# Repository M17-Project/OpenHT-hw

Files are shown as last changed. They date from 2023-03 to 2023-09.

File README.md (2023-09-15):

# OpenHT-hw
Hardware part of the OpenHT - an open-source, SDR handheld transceiver.

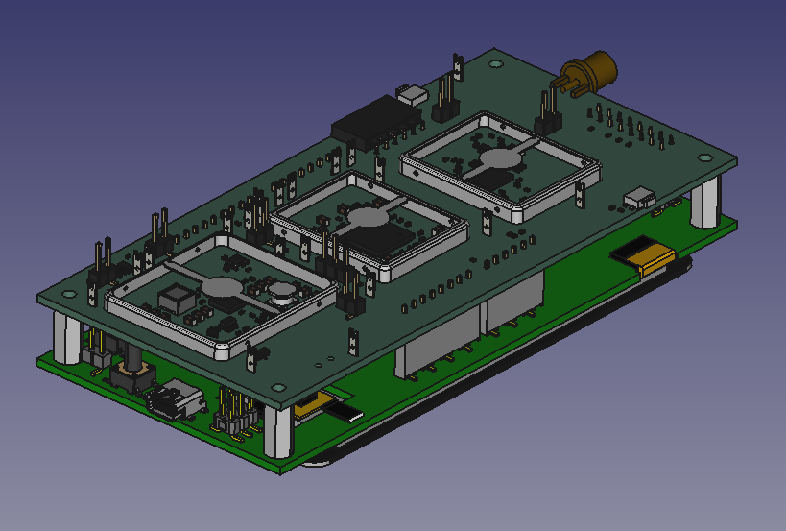
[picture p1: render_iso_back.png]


## Description
The device is a complete, low RF power I/Q transceiver, supporting virtually any mode (including [M17](https://m17project.org) and [FreeDV](https://freedv.org)).
It is built around the [AT86RF215 chip](https://www.microchip.com/en-us/product/AT86RF215) by Microchip/Atmel
and [LIFCL-40-9SG72C](https://www.latticesemi.com/Products/FPGAandCPLD/CrossLink-NX) FPGA from Lattice as a shield for [32F469IDISCOVERY](https://www.st.com/en/evaluation-tools/32f469idiscovery.html). It is possible to use the board with other MCU platforms.

Technical details:
- frequency range: 389.5 - 480, 2400 - 2483.5 MHz (RX, TX frequency range is limited by your local laws)
- RF power output: <14dBm (<25mW)

## Assembly tips and U204 issue
After the board has been populated, perform the steps below:
1) Remove JP201 (undervoltage lock-out).
2) Remove U204 (you need to take the lower shield off).
3) Using a copper wire, connect `VIN` and `VBAT`.
4) Secure goldpin headers in place by putting them on the DISCO board (Arduino male connector and the 2x8 female connector) and solder them.
5) Populate JP401 and short the two left pins,`JTAG_EN` to `GND`, "OFF" position.
6) Prepare a micro-SD card with the FPGA image, its filename should be `OpenHT_impl_1.bit`. The SD card has to be preformatted with FAT32.
7) Plug the mini-USB port and flash the firmware from the `main` branch.
8) In the GUI, tap on the cog icon (upper left corner), then press the `Erase NOR` button. After a few seconds (about 3), press the `SD to NOR` button and wait a few seconds more.
9) After the flashing is done, press and hold the power-on button for at least 1.5 seconds. The "LED" next to the cog icon should light up in green.

Step 8) needs to be performed only *once* for a fresh FPGA image. After that, the image is transferred to the NOR flash and is supposed to be retrieved by the FPGA automagically.
It is highly recommended to use terminal for getting debug info. The terminal is 115,200 baud, 8n1, over the COM port exposed by the DISCO board.

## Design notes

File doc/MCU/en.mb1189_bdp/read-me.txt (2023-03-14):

******************************************************************************
* @file    readme.txt
* @author  MCD Application Team
* @version 3.0
* @date    11-March-2022  
* @brief   MB1189 board design project files package
******************************************************************************
* COPYRIGHT(c) 2022 STMicroelectronics
*
* The Open Platform License Agreement (“Agreement”) is a binding legal contract
* between you ("You") and STMicroelectronics International N.V. (“ST”), a
* company incorporated under the laws of the Netherlands acting for the purpose
* of this Agreement through its Swiss branch 39, Chemin du Champ des Filles,
* 1228 Plan-les-Ouates, Geneva, Switzerland.
*
* By using the enclosed reference designs, schematics, PC board layouts, and
* documentation, in hardcopy or CAD tool file format (collectively, the
* “Reference Material”), You are agreeing to be bound by the terms and
* conditions of this Agreement. Do not use the Reference Material until You
* have read and agreed to this Agreement terms and conditions. The use of
* the Reference Material automatically implies the acceptance of the Agreement
* terms and conditions.
*
* The complete Open Platform License Agreement can be found on www.st.com/opla.
******************************************************************************

========================
* 2.0 -  11-March-2022 
========================
    + Added revision B-08 with FRD400B25025-A-CTK display
    - Allegro design files

    + Added revision C-01.
    - Altium design files

========================
* 1.0 - 13-January-2016
========================
    + First official release with Rev B-07 .
    - Allegro design files

******************* (C) COPYRIGHT 2022 STMicroelectronics *****END OF FILE

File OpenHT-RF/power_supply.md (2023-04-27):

# Design and dimensioning of the power supply stage

## Electrical requirements

* Three output rails:
    * 3.3 V
    * 1.8 V
    * 1.0 V

* FPGA requirements
    * Manufacturer recommends a regulation accurate within 3% of the optimum voltage for the DC power supplies
        * 3.3 V -> [3.2 V - 3.4 V], or deviation of maximum 99 mV
        * 1.8 V -> [1.746 V - 1.854 V], or deviation of maximum 54 mV
        * 1.0 V -> [0.97 V - 1.03 V], or deviation of maximum 30 mV
    * An additional recommendations advices to target less than 0.25% peak noise for the PLLs supplies. In this project, only VCCPLL_ULC is connected and supplied with 1.0 V. This implies a maximum voltage ripple on the 1.0 V rail of 2.5 mV.

    Thus the 1.0 V must be particularly noise-free.

## Choice of components

It was decided to pick a buck converter to keep a good power efficiency. The triple-output buck TPS65261 from Texas Instrument was picked because it fills the constraint of being low quiescent current, input voltage range comprising 6 V-8.4 V (for a 2-cells lithium battery) and good light-load efficiency. However, at light load, the output voltage ripple can become quite important (about 20 mV). This could cause problems for the 1.0 V of the FPGA which requires an input voltage with an error margin of +-3%. Thus the 1.0 V rail will be derived from the 1.8 V rail using a high PSRR LDO.

## Buck-converter dimensioning

### Common

 * Switching frequency: 400kHz -> Rosc = 110 kR
 * Soft start: ~1 ms -> Css = 18 nF
 * UVLO: when Vbat reaches 6 V (6.0 V falling, 6.2 V rising)
    * R1 = 200 kR
    * R2 = 47.58 kR -> 47.5kR
    * Reverse calculation gives 6.209 V rising, 6.009 V falling

### Buck 1

 * Output: 3.3 V -> R1 = 9.53 kR, R2 = 43 kR (0.1% tolerance)

    |        | Min.    | Nom.    | Max.    |
    |--------|---------|---------|---------|
    | V      | 3.269 V | 3.307 V | 3.346 V |
    | %      | -0.95   | 0.22    | 1.39    |
    | Margin | 68 mV   |         | 53 mV   |

    N.B. The tolerance takes into account the tolerance of the feedback voltage reference (1%).

 * Output current: 500 mA (max. for MCU is 290 mA, max for Xcver is 80 mA. Keep room for the rest of the system (audio, FPGA, ...))
 Switching 

 * Inductor choice 
    * Value: 33 uH (LIR = 0.3)
        * Iripple = 150 mA
        * ILrms = 501 mA
        * ILpeak = 575 mA
        * ILpeak(PSM mode) = 230 mA
    The reference LSXND5050XKT330MMG is pre-picked. Max current is 800 mA, saturation current is 1.15 A, series resistance is 225 mOhm (295 mOhm max.).
* Output capacitor
    * Based on modulator pole: Does not really influence loop compensation calculation.
    * Based on Vout ripple: Voripple of 2% of 3.3 V -> 0.7uF, max Resr of 0.45 Ohm.
    * Based on load regulation: Max drop in Vout of 2% for an increase in current of 100 mA (i.e. a bit more than the Xcvr transmitting) -> 7.5 uF

    The minimum output capacitor value should therefore be 7.5 uF. The Resr should be below 0.45 Ohm. Several capacitors should be placed in parallel to help satisfy this requirement.
    Use 3 ceramic capacitors of 4.7 uF with X5R or better dielectric.

* Input capacitor
    * Using the same capacitor network as the output capacitor would lead to 22 mV of input ripple. 
    * It is recommended to use a large enough footprint so that this value can be increased later on if needed.

* Loop compensation
    * Cross over frequency fc = 1/10 of fsw or 40 kHz
    * Rc = 1595 Ohm -> rounded to 1600 Ohm
    * Cc (Rl = 3.3 V/0.5 A = 6.6 Ohm) = 58 nF, rounded up to 68 nF
    * Cb = 29 pF, rounded down to 27 pF (for a Resr of 3.3 mOhm)
    * Cff = 460 pF (https://www.ti.com/lit/an/slva466a/slva466a.pdf), rounded to 470 pF

 ### Buck 2

 * Output: 1.8V -> R1 = 10 kR, R2 = 20 kR (0.1% tolerance)

    |        | Min.    | Nom.  | Max.   |
    |--------|---------|-------|--------|
    | V      | 1.779 V | 1.8 V | 1.82 V |
    | %      | -1.13   | 0     | 1.13   |
    | Margin | 33 mV   |       | 34 mV  |

    N.B. The tolerance takes into account the tolerance of the feedback voltage reference (1%).
 * Output current: 250 mA. Picking a lower current would not make much sense as the devices goes into PSM when below 230 mA.

 * Inductor choice
    * Value: 47 uH (LIR = 0.3)
        * Iripple = 75 mA
        * ILrms = 251 mA
        * ILpeak = 288 mA
        * ILpeak (PSM) = 230mA

    The reference 74406043470 is pre-picked. Max current is 970 mA, saturation current is 560 mA, series resistance is 260 mOhm.

* Output capacitor   
    * Based on modulator pole: Does not really influence loop compensation calculation.
    * Based on Vout ripple: Voripple of max 25mV -> 0.94uF, max Resr of 0.33 Ohm.
    * Based on load regulation: Max drop in Vout of 25mV for an increase in current of 30 mA -> 6uF

    The minimum output capacitor value should therefore be 6 uF. The Resr should be below 0.33 Ohm. Several capacitors should be placed in parallel to help satisfy this requirement.
    Use 2 ceramic capacitors of 4.7 uF with X5R or better dielectric.

* Input capacitor
    * Using the same capacitor network as the output capacitor would lead to 16 mV of input ripple. 
    * It is recommended to use a large enough footprint so that this value can be increased later on if needed.

* Loop compensation
    * Cross over frequency fc = 1/10 of fsw or 40 kHz
    * Rc = 1063 Ohm -> rounded to 1000 Ohm
    * Cc (Rl = 1.8 V/0.25 A = 7.2 Ohm) = 67 nF, rounded up to 68 nF
    * Cb = 47 pF (for a Resr of 5 mOhm)
    * Cff = 487 pF (https://www.ti.com/lit/an/slva466a/slva466a.pdf), rounded to 470 pF

## 1.0 V LDO

* Divider bridge
    Output = 1.0V, feedback = 0.8V at 1% accuracy

    |        | Min.    | Nom. | Max.    |
    |--------|---------|------|---------|
    | V      | 0.989 V | 1    | 1.01 V  |
    | %      | -1.04   | 0    | 1.04    |
    | Margin | 19.6 mV |      | 19.6 mv |

-- Morgan ON4MOD

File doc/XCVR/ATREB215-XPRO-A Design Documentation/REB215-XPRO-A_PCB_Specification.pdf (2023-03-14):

TITLE: | PCB Specification
NUMBER: | HWDR2-006
PCB Specification | Page 1 of 6 | Template Revision: 1 Live Revision: A

ATMEL CONFIDENTIAL

# ATREB215-XPRO-A PCB Specification

PCB Specification | Page 2 of 6 | Template Revision: 1

## Table of Contents

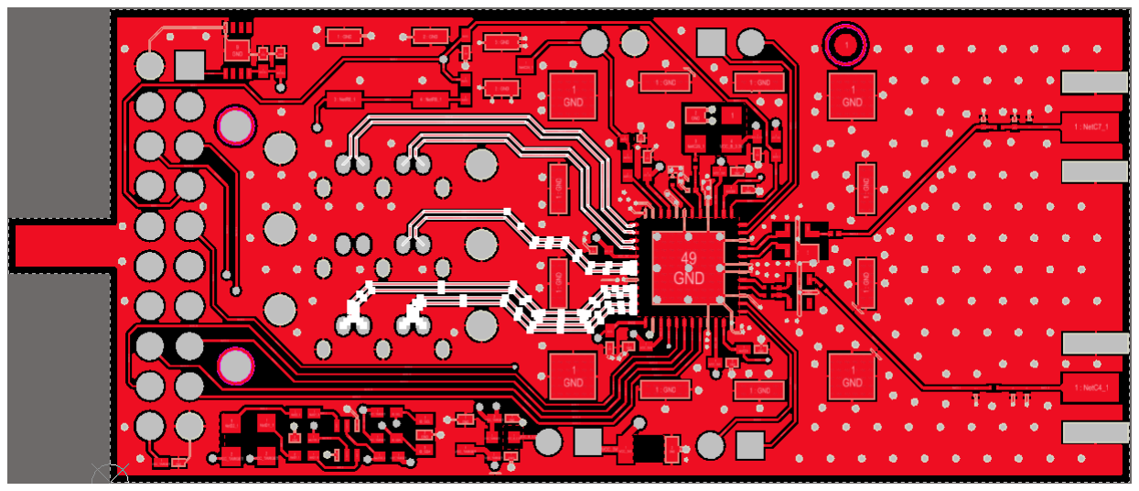
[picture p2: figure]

PCB Specification | Page 3 of 6 | Template Revision: 1

## 1 General information

### 1.1 Board identification

Name: ATREB215-XPRO-A Extension Board Board identification number: A08-2463 Rev1

## 2 PCB specification

### 2.1 Manufacturing data

- Size: 30mm x 71.5mm
- PCB material: S1000
- Layers: 4
- Finish: ENIG
- Minimum via hole size: 0.15 mm
- Minimum via pad size: 0.35 mm
- Minimum track width: 0.1 mm (3.936mil)
- Minimum spacing: 0.15 mm (5.905mil)
- Solder mask color: Dark BLUE
- Silk-screen color: White
- Controlled impedance for LVDS tracks on top layer with 50 Ohms single ended and 100 Ohms differential (Highlighted track)

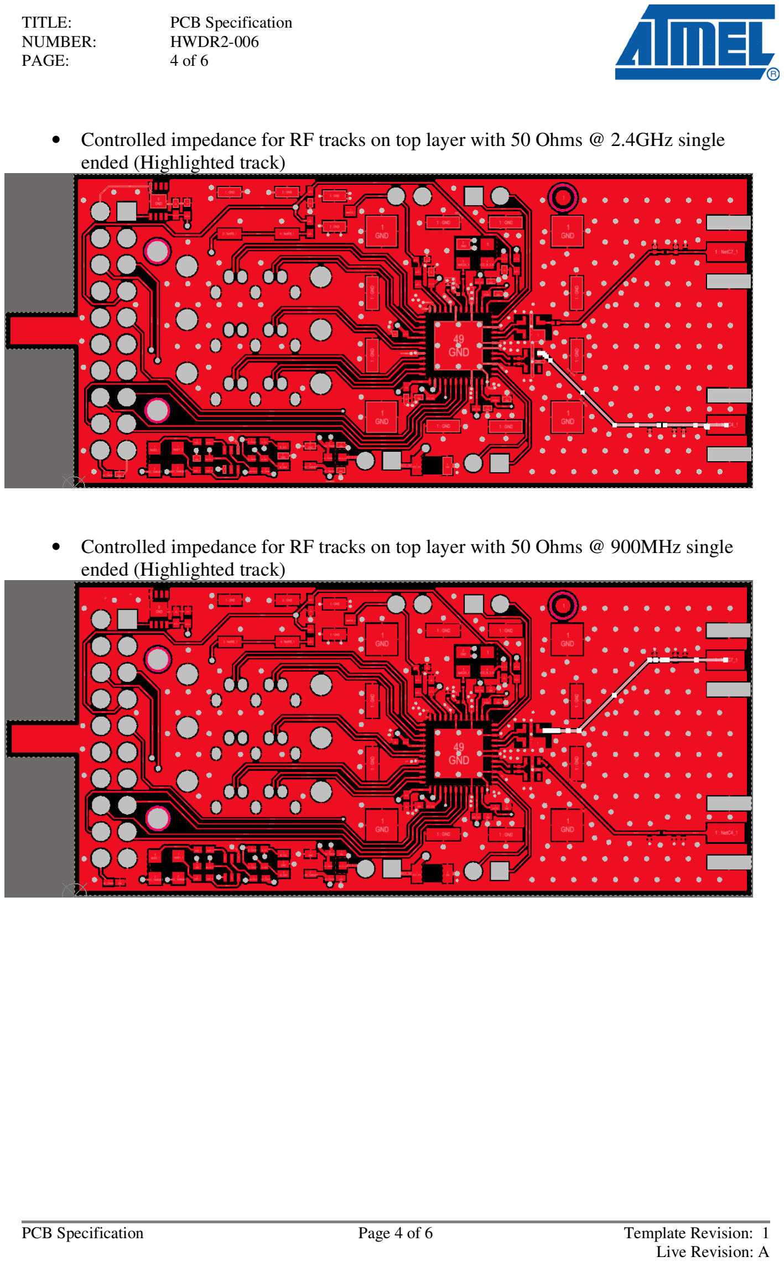
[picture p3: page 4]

PCB Specification | Page 4 of 6 | Template Revision: 1
- Controlled impedance for RF tracks on top layer with 50 Ohms @ 2.4GHz single ended (Highlighted track)
- Controlled impedance for RF tracks on top layer with 50 Ohms @ 900MHz single ended (Highlighted track)

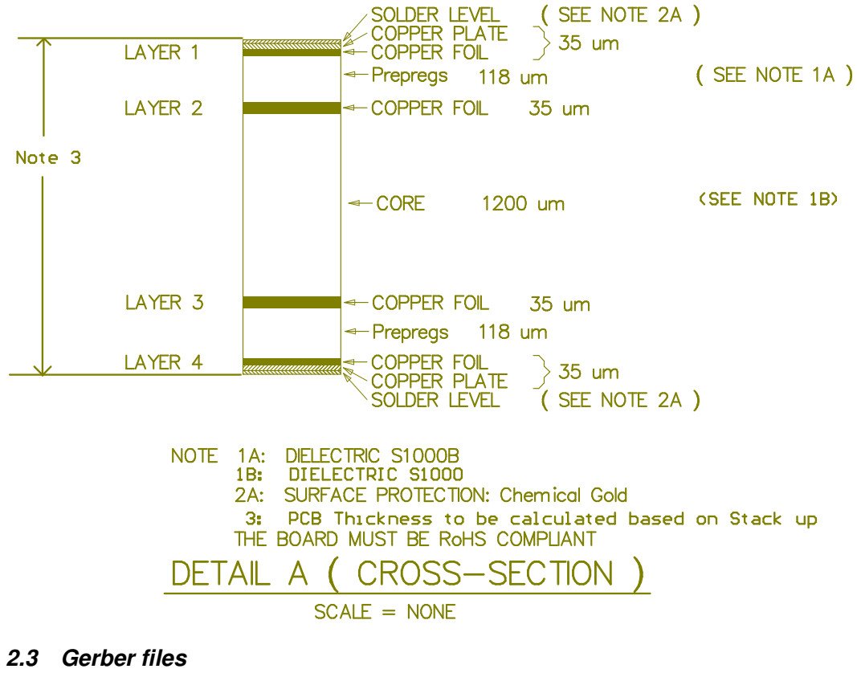
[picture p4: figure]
2.3 Gerber files

PCB Specification | Page 5 of 6 | Template Revision: 1

### 2.2 Layer stack up

Figure Figure 2-1 shows the detailed layer stack up for this PCB.
Figure 2-1 Detailed layer stack up

Table 2-1 Layer stack up corresponding Gerber files (listed from top to bottom)
File name | Description
REB215_XPRO_A.GTP | Gerber file for top paste-mask
REB215_XPRO_A.GTO | Gerber file for top overlay (silkscreen)
REB215_XPRO_A.GTS | Gerber file for top solder-mask
REB215_XPRO_A.GTL | Gerber file for top layer
REB215_XPRO_A.G1 | Gerber file for Mid layer 1
REB215_XPRO_A.G2 | Gerber file for Mid layer 2
REB215_XPRO_A.GBL | Gerber file for bottom signal layer
REB215_XPRO_A.GBS | Gerber file for bottom solder-mask
REB215_XPRO_A.GBO | Gerber file for bottom overlay (silkscreen)

PCB Specification | Page 6 of 6 | Template Revision: 1
REB215_XPRO_A.GBP | Gerber file for bottom paste-mask
REB215_XPRO_A.GM1 | Gerber file for mechanical 1 layer (board outline)
REB215_XPRO_A.DRR | Drill file report
REB215_XPRO_A.TXT | Drill file

### 2.4 Special via considerations

All vias are covered with solder mask on the top side of the board. On the bottom side vias that are used as test points have openings in the solder mask.

### 2.5 Placement of fabrication ID mark

The fabrication ID mark should be placed on the bottom side.

## 3 Panelizing

When making panels for this board the following issues should be considered.
- Fiducial marks should be placed on the panel.

## 4 Quality of silkscreen layers

The silkscreen layers for the PCB must be of high quality for several reasons:
- Very small text is used
- Text is close to pads and therefore the mask must be centered properly on the board
- The PCB is used for development boards and therefore the silkscreen is an essential part of the overall product quality.

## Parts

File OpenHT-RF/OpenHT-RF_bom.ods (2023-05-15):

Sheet: OpenHT-RF
# | Reference | Qty | Value | Footprint | DNP | MPN | Dielectric | Rated voltage | Tolerance
1 | C101, C201, C205, C220, C225, C426, C508, C514, C515 | 9 | 1uF | Capacitor_SMD:C_0402_1005Metric |  | Generic C/1uF/0402/X5R/10V
2 | C202 | 1 | 18nF | Capacitor_SMD:C_0402_1005Metric |  | Generic C/18nF/0402/X7R/10V
3 | C203, C204 | 2 | 0.15uF | Capacitor_SMD:C_0402_1005Metric |  | Generic C/0.15uF/0402/X5R/10V
4 | C206, C208, C209, C210, C211, C218, C219, C221, C222, C223 | 10 | 4.7uF | Capacitor_SMD:C_0805_2012Metric |  | Generic C/0.15uF/0805/X5R/25V | X5R or better | 50V or higher
5 | C207, C224 | 2 | 4.7uF | Capacitor_SMD:C_0805_2012Metric | DNP | Generic C/0.15uF/0805/X5R/25V | X5R or better | 50V or higher
6 | C212 | 1 | 3.9pF | Capacitor_SMD:C_0402_1005Metric |  | Generic C/3.9pF/0402/C0G/10V
7 | C213 | 1 | 4.5pF | Capacitor_SMD:C_0402_1005Metric |  | Generic C/4.5pF/0402/C0G/10V
8 | C214, C215 | 2 | 47nF | Capacitor_SMD:C_0402_1005Metric |  | Generic C/47nF/0402/X5R/10V | X5R or better
9 | C216 | 1 | 1.2nF | Capacitor_SMD:C_0402_1005Metric |  | Generic C/1.2nF/0402/X7R/10V
10 | C217, C504 | 2 | 1nF | Capacitor_SMD:C_0402_1005Metric |  | Generic C/1nF/0402/X7R/10V
11 | C226 | 1 | 6.8nF | Capacitor_SMD:C_0402_1005Metric |  | Generic C/6.8nF/0402/X5R/10V
12 | C227, C301, C406, C407, C408, C409, C410, C411, C412, C413, C414, C415, C417, C418, C420, C421, C422, C427, C428, C501, C517, C518, C519, C520, C521 | 25 | 0.1uF | Capacitor_SMD:C_0402_1005Metric |  | Generic C/0.1uF/0402/X7R/16V
13 | C228, C229 | 2 | 470pF | Capacitor_SMD:C_0402_1005Metric |  | Generic C/470pF/0402/X7R/16V
14 | C401, C402, C403, C404, C405, C416, C419, C425, C522 | 9 | 10uF | Capacitor_SMD:C_0805_2012Metric |  | Generic C/10uF/0805/X5R/10V
15 | C423 | 1 | 10uF | Capacitor_SMD:C_0805_2012Metric | DNP | Generic C/10uF/0805/X5R/10V
16 | C424 | 1 | 0.1uF | Capacitor_SMD:C_0402_1005Metric | DNP | Generic C/0.1uF/0402/X7R/16V
17 | C502, C503 | 2 | 1.8pF | Capacitor_SMD:C_0402_1005Metric |  | Generic C/1.8pF/0402/C0G/10V | C0G
18 | C505 | 1 | 1nF | Capacitor_SMD:C_0402_1005Metric |  | Generic C/1nF/0402/C0G/10V | C0G
19 | C506 | 1 | 10pF | Capacitor_SMD:C_0402_1005Metric |  | Generic C/10pF/0402/C0G/10V | C0G
20 | C507 | 1 | 0.8pF | Capacitor_SMD:C_0402_1005Metric |  | Generic C/0.8pF/0402/C0G/10V | C0G
21 | C509, C510, C513 | 3 | 100pF | Capacitor_SMD:C_0402_1005Metric |  | Generic C/100pF/0402/C0G/10V | C0G
22 | C511 | 1 | 220pF | Capacitor_SMD:C_0402_1005Metric |  | Generic C/220pF/0402/C0G/10V | C0G
23 | C512 | 1 | 82pF | Capacitor_SMD:C_0402_1005Metric |  | Generic C/82pF/0402/C0G/10V | C0G
24 | C516 | 1 | 2.2pF | Capacitor_SMD:C_0402_1005Metric |  | Generic C/2.2pF/0402/C0G/10V | C0G
25 | C523 | 1 | 1nF | Capacitor_SMD:C_0402_1005Metric | DNP | Generic C/1nF/0402/X7R/10V
26 | D301 | 1 | BAT60A | Diode_SMD:D_SOD-323 |  | BAT60AE6327HTSA1
27 | D501 | 1 | D_TVS | M17_misc_passive:D_Toshiba_CST2 |  | DF2B5M4CT,L3F
28 | F201 | 1 | Polyfuse | Fuse:Fuse_1812_4532Metric |  | SMD1812B200TF/16
29 | FB401, FB402, FB403, FB501 | 4 | BLM15AG121SN1D | Inductor_SMD:L_0402_1005Metric |  | BLM15AG121SN1D
30 | FB404 | 1 | BLM15AG121SN1D | Inductor_SMD:L_0402_1005Metric | DNP | BLM15AG121SN1D
31 | FL501 | 1 | LFCN-490+ | Filter:Filter_Mini-Circuits_FV1206 |  | LFCN-490+
32 | FL502 | 1 | LFCN-2500+ | Filter:Filter_Mini-Circuits_FV1206 |  | LFCN-2500+
33 | J202 | 1 | MS338-10F | M17_misc_passive:MS338-10F |  | MS338-10F
34 | J402, J504 | 2 | MS300-10F | M17_misc_passive:MS300-10F |  | MS300-10F
35 | JP201, JP202, JP203, JP204 | 4 | Jumper_2_Bridged | Connector_PinHeader_2.54mm:PinHeader_1x02_P2.54mm_Vertical_SMD_Pin1Right |  | 10129380-902001BLF or equivalent
36 | L201 | 1 | 33uH | M17_misc_passive:L_Taiyo-Yuden_NR-5030 |  | LSXND5050XKT330MMG
37 | L202 | 1 | 47uH | M17_misc_passive:L_Wurth_WE-LQSF-4828 |  | 74406043470
38 | L501 | 1 | 5.6nH | Inductor_SMD:L_0402_1005Metric |  | LRC0402CS5N6GV001T
39 | L502 | 1 | 2450FB15A050 | M17_misc_passive:2450FB15A050 |  | 2450FB15A0050001E
40 | L503 | 1 | ATB2012-50011 | M17_misc_passive:ATB2012 |  | ATB2012-50011-T000
41 | Q201 | 1 | DMP3099L-7 | Package_TO_SOT_SMD:SOT-23 |  | DMP3099L-7
42 | R101, R202 | 2 | 1kR | Resistor_SMD:R_0402_1005Metric |  | Generic R/1kR/0402/1% |  |  | 1%
43 | R201, R312 | 2 | 200kR | Resistor_SMD:R_0402_1005Metric |  | Generic R/200kR/0402/1% |  |  | 1%
44 | R203 | 1 | 47.5kR | Resistor_SMD:R_0402_1005Metric |  | Generic R/47.5kR/0402/1% |  |  | 1%
45 | R204 | 1 | 110kR | Resistor_SMD:R_0402_1005Metric |  | Generic R/110kR/0402/1% |  |  | 1%
46 | R205, R206, R317, R502 | 4 | 100kR | Resistor_SMD:R_0402_1005Metric |  | Generic R/100kR/0402/1% |  |  | 1%
47 | R207 | 1 | 1.6kR | Resistor_SMD:R_0402_1005Metric |  | Generic R/1.6kR/0402/1% |  |  | 1%
48 | R208 | 1 | 3.16kR | Resistor_SMD:R_0402_1005Metric |  | Generic R/3.16kR/0402/1% |  |  | 1%
49 | R209 | 1 | 43kR | Resistor_SMD:R_0402_1005Metric |  | Generic R/43kR/0402/0.1% |  |  | 0.1% or better
50 | R210 | 1 | 9.53kR | Resistor_SMD:R_0402_1005Metric |  | Generic R/9.53kR/0402/0.1% |  |  | 0.1% or better
51 | R211 | 1 | 20kR | Resistor_SMD:R_0402_1005Metric |  | Generic R/20kR/0402/0.1% |  |  | 0.1% or better
52 | R212 | 1 | 10kR | Resistor_SMD:R_0402_1005Metric |  | Generic R/10kR/0402/0.1% |  |  | 0.1% or better
53 | R213 | 1 | 2.55kR | Resistor_SMD:R_0402_1005Metric |  | Generic R/2.55kR/0402/1% |  |  | 1%
54 | R214 | 1 | 10.2kR | Resistor_SMD:R_0402_1005Metric |  | Generic R/10.2kR/0402/0.1% |  |  | 0.1%
55 | R215, R301, R302, R303, R304, R305, R306, R307, R308, R309, R310, R311, R313, R314, R315, R316, R402, R504 | 18 | 100R | Resistor_SMD:R_0402_1005Metric |  | Generic R/100R/0402/1% |  |  | 1%
56 | R401, R501 | 2 | 10kR | Resistor_SMD:R_0402_1005Metric |  | Generic R/10kR/0402/1% |  |  | 1%
57 | R503 | 1 | 220R | Resistor_SMD:R_0402_1005Metric |  | Generic R/220R/0402/1% |  |  | 1%
58 | SW101, SW201 | 2 | 436351045816 | M17_misc_passive:SW_SPST_436351045816 |  | 436351045816
59 | SW501 | 1 | RFSW8008 | M17_misc_active:RFSW8008 |  | RFSW8008TR7
60 | U201 | 1 | LTC2954-1 | Package_TO_SOT_SMD:TSOT-23-8 |  | LTC2954CTS8-1#TRMPBF
61 | U202 | 1 | TPS65261RHBx | M17_QFN:VQFN-32-1EP_5x5mm_P0.5mm_EP3.45x3.45mm_ThermalVias |  | TPS65261RHBR
62 | U203 | 1 | AP7330-W5-7 | Package_TO_SOT_SMD:SOT-23-5 |  | AP7330-W5-7
63 | U204 | 1 | TPS22810DBVR | Package_TO_SOT_SMD:SOT-23-6 |  | TPS22810DBVR
64 | U401 | 1 | LIFCL-40-9SG72C | M17_QFN:QFN-72-1EP_10x10mm_P0.5mm_EP6.2x6.2mm_ThermalVias |  | LIFCL-40-9SG72C
65 | U501 | 1 | AT86RF215 | M17_QFN:VQFN-48-1EP_7x7mm_P0.5mm_EP5.6x5.6mm_ThermalVias |  | AT86RF215-ZU
66 | X501 | 1 | ECS-TXO-20CSMV | M17_misc_active:ECS-TXO-20CSMV |  | ECS-TXO-20CSMV-260-AY-TR

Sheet: OpenHT-RF_manual
# | Reference | Qty | Value | Footprint | DNP | MPN | Dielectric | Rated voltage | Tolerance
1 | J201 | 1 | Conn_01x02 | TerminalBlock_4Ucon:TerminalBlock_4Ucon_1x02_P3.50mm_Horizontal
2 | J203 | 1 | MS338-10C |  |  | MS338-10C
3 | J301 | 1 | Conn_01x06 | Connector_PinHeader_2.54mm:PinHeader_1x06_P2.54mm_Vertical
4 | J302, J305 | 2 | Conn_01x08 | Connector_PinHeader_2.54mm:PinHeader_1x08_P2.54mm_Vertical
5 | J303 | 1 | Conn_02x08_Odd_Even | Connector_PinSocket_2.54mm:PinSocket_2x08_P2.54mm_Vertical
6 | J304 | 1 | Conn_01x10 | Connector_PinHeader_2.54mm:PinHeader_1x10_P2.54mm_Vertical
7 | J401 | 1 | Conn_01x06 | Connector_PinSocket_2.54mm:PinSocket_1x06_P2.54mm_Horizontal | DNP
8 | J403, J505 | 2 | MS300-10C |  |  | MS300-10C
9 | J501 | 1 | EMPCB.CSMAFSTJ.A | M17_connectors:SMA_Taoglas_EMPCB.CSMAFSTJ.A |  | EMPCB.CSMAFSTJ.A
10 | J502, J503 | 2 | Conn_01x02 | Connector_PinHeader_2.54mm:PinHeader_1x02_P2.54mm_Vertical | DNP
11 | JP401 | 1 | Jumper_3_Bridged12 | Connector_PinHeader_2.54mm:PinHeader_1x03_P2.54mm_Vertical
12 | LS101 | 1 | SP-1605 | M17_connectors:Pin_1x02_P2.54mm_horizontal_SMD |  | SP-1605

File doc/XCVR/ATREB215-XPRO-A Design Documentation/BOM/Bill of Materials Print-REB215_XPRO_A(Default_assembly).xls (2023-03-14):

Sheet: Part List Report
 | Component list |  | Bill of Materials Print For Variant [Default_assembly] of Project [REB215_XPRO_A.PrjPCB] (No PCB Document Selected)
 | Source Data From: |  | REB215_XPRO_A.PrjPCB
 | Project: |  | REB215_XPRO_A.PrjPCB
 | Variant: |  | Default_assembly
 | Report Date: | 2/3/2016 | 7:43:22 PM
 | Print Date: | 2/3/2016 | 7:42:37 PM
Fitted | Designator | Quantity | Value | Manufacturer | MPN | Description
Fitted | B1 | 1 | 2450FB15A050 | Johanson Technology | 2450FB15A050 | 2.45 GHz Balun / Filter Combination
Fitted | B2 | 1 | 0896BM15E0025E | Johanson Technology | 0896BM15E0025E | 863/915 MHz ISM band Balun+LPF for AT86RF215
Fitted | C1, C9, C11, C13, C14, C15, C16, C17 | 8 | 100n | Kemet | C0402C104K4RACTU | Ceramic capacitor, SMD 0402, X7R, 16V, +/-10%
Fitted | C2, C12 | 2 | 1.8pF | Johanson Technology | 250R05L1R8BT4T | CAP CER 1.8PF 25V NP0 0201
Fitted | C3 | 1 | 0.8pF | Johanson Technology | 250R05L0R8AV4T | CAP CER 0.8PF 25V NP0 0201
Fitted | C6 | 1 | 4.7n |  |  | Ceramic capacitor, SMD 0402, X7R, 25V, +/-10% (de35287)
Fitted | C8 | 1 | 15pF | Murata | GRM0335C1E150JA01D | CAP CER 15PF 25V NP0 0201
Fitted | C10 | 1 | 10pF | tdk | C0603C0G1E100C | CAP CER 10PF 25V Â±.25pf ( and Â±.30ppm/ degree C of temp variation) NP0 0201
Fitted | C18, C19, C20 | 3 | 1u | Kemet | C0402C105K9PAC | Ceramic capacitor, SMD 0402, X5R, 6.3V, +/-10% (de26942)
Fitted | C23 | 1 | 10u | Murata | GRM319R60J106KE19 | Ceramic capacitor, SMD 1206, X5R, 6.3V, ±10%
Fitted | C24 | 1 | 2.2pF | Murata | GRM1555C1H2R2CZ01D | Ceramic capacitor, SMD 0402, NP0, 50V, +/-0.25pF (de23847)
Fitted | C25 | 1 | 1nF | Johanson Technology | 100R05W102KV4 | Ceramic capacitor, SMD 0201, X7R, 10V, +/-10%
Fitted | C100, C101 | 2 | 4.7uF | Murata | GRM155R60J475ME87D | Ceramic capacitor, SMD 0402, X5R, 6.3V, +/-20% (de33687)
Fitted | D1 | 1 | EL17-21SYGC | Everlight | EL17-21SYGC | LED, Green, Wave length=575nm, SMD 0805, ±70°
Fitted | D2 | 1 | EL17-21UYC/A3 | Everlight | 17-21UYC/S530-A3/TR8 | LED, Yellow, Wave length=591nm, SMD 0805, ±70°
Fitted | E1, E2, E3 | 3 | SJ-5076 | 3M | SJ-5076 | 2.8mm adhesive feet,diam 8.0mm
Fitted | J1, J104, J105 | 3 | HMTSW-102-23-F-S-237 | SAMTEC | HMTSW-102-23-F-S-237 | 1x2 pin header, 2.54mm pitch, Pin-in-Paste THM
Fitted | J100 | 1 | F201-2*10RGF-W2-NF | Pro-data International Corp | F201-2*10RGF-W2-NF | 2x10, female pin header receptable, right-angled, 2.54mm pitch, THM, Pin In Paste
Fitted | J101, J102, J103 | 3 | 67491-1030 | Molex | 67491-1030 | 1.27mm Pitch Serial ATA High Speed Header, Through Hole, Vertical, 7 Circuits
Fitted | JS1 | 1 | SNT-100-BK-G | SAMTEC | SNT-100-BK-G | Jumper cap for 2.54mm pinheader
Fitted | L2 | 1 | 74279263 | Wurth Elektronik | 74279263 | SMD-Ferrite 220Ohm, 100MHz 0603 size, (de14411)
Fitted | L3 | 1 | 5.6nH | Johanson Technology | L-05B5N6SV6T | ceramic chip inductor, 5.6nH, 0201
Fitted | LABEL1 | 1 | 505462 | ACT Logimark AS | 505462 | Label for use on wireless PCBA that needs IC ID and FCC ID
Fitted | P1 | 1 | U.FL-R-SMT-1(10) | HIROSE | U.FL-R-SMT-1(10) | UFL (Small Coax Connector)
Fitted | Q1 | 1 | 2N7002DW | Fairchild | 2N7002DW | Dual N-Channel MOSFET, 60V, 115mA cont,RDS(ON) < 7.5 Ohm @50mA@5V, SOT-363
Fitted | R1, R5 | 2 | 1M |  |  | Thick film resistor, SMD 0402, 1/16W, 1%
Fitted | R2, R3 | 2 | 330R |  |  | Thick film resistor, SMD 0402, 1/16W, 1%
Fitted | R4, R9 | 2 | 0R | ROHM | MCR006YZPJ000 | Thick film resistor, SMD 0201, 1/20W, 5%
Fitted | R6, R100 | 2 | 100k |  |  | Thick film resistor, SMD 0402, 1/16W, 1%
Fitted | R7 | 1 | 100K | YAGEO CORP | RC0201JR-07100KL | RES 100K OHM 1/20W 5% 0201 SMD
Fitted | R8 | 1 | 39R |  |  | Thick film resistor, SMD 0402, 1/16W, 1%
Fitted | R10, R11, R13 | 3 | 10 k | ROHM | MCR006YZPJ103+ | Thick film resistor, SMD 0201, 1/20W, 5%
Fitted | R12 | 1 | 220R |  |  | Thick film resistor, SMD 0402, 1/16W, 1%
Fitted | R101, R102 | 2 | 10k | vishay | CRCW040210K0FKED | Thick film resistor, SMD 0402, 1/16W, 1%
Fitted | SMA1, SMA2 | 2 | 142-0711-821 | EMERSON | 142-0711-821 | End Launch Jack Receptacle, Round Contact (de21535)
Fitted | SW1 | 1 | SKRAAKE010 | ALPS | SKRAAKE010 | SWITCH, SMD, 2.45N, 6.2mm X 6.2mm
Fitted | U1 | 1 | AT86RF215-ZU | ATMEL | AT86RF215-ZU | Sub-1GHz/2.4GHz Transceiver
Fitted | U2 | 1 | AT24MAC602-STUM-T | ATMEL | AT24MAC602-STUM-T | IC EEPROM 2KBIT 1MHz, 1.7V to 5.5V, SOT23-5
Fitted | U100 | 1 | ATSHA204A SWI UDFN8 | ATMEL | ATSHA204A-MAHCZ-T | ATSHA204A with 1-wire interface and UDFN8 package
Fitted | XC1 | 1 | 26.0 MHz | Taiway Electronics | TXETCCSANF-26.0000 | 26MHz TCXO, 2.8 ~ 3.3V, Clipped sine wave 10KOhm/10pF, 3.2 x 2.5 mm SMD
Not Fitted | C4, C21 | 0 | 1.2pF | Johanson Technology | 250R05L1R2CV4T | Ceramic Capacitor, SMD 0201, 25V, NP0, 1.2pF
Not Fitted | C7, C22 | 0 | 2.2 pF | Kemet | CBR02C229C9GAC | CAP CER 2.2PF 6.3V NP0 0201
Not Fitted | FR1 | 0 | LT11BH2611F | Laird Technologies | LT11BH2611F | SMD frame for metal shield 20mm x 20mm (de34031)
 |  | 65
Approved |  |  | Notes

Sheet: Project Information
Project Full Path | D:\RF215\PCB\Web_Release\Altium Design Files_REB215_XPRO-A\REB215_XPRO_A.PrjPCB
Project Filename | REB215_XPRO_A.PrjPCB
Variant Name | Default_assembly
Data-Source Filename | REB215_XPRO_A.PrjPCB
Data-Source Full Path | D:\RF215\PCB\Web_Release\Altium Design Files_REB215_XPRO-A\REB215_XPRO_A.PrjPCB
Title | Bill of Materials Print For Variant [Default_assembly] of Project [REB215_XPRO_A.PrjPCB] (No PCB Document Selected)
Total Quantity | 65
Report Time | 7:43:22 PM
Report Date | 2/3/2016
Report Date & Tine | 2/3/2016 7:43:22 PM
Output Name | Bill of Materials Print
Output Type | BOM_PartType
Output Generator Name | BOM
Output Generator Description | Bill of Materials

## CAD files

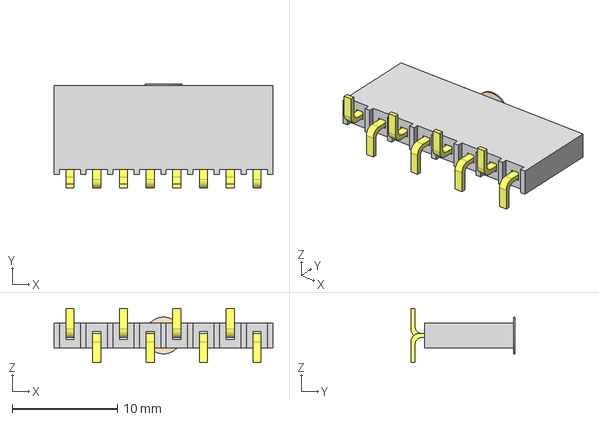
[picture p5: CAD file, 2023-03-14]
doc/MCU/en.mb1189_bdp/MB1189_C01/SSW-108-22-G-S-VS-K-TR.stp
20.8 x 9.91 x 5.16 mm
P2SSW-108-22-G-S-VS
T1SSW-108-22-G-S-VS-K-TR

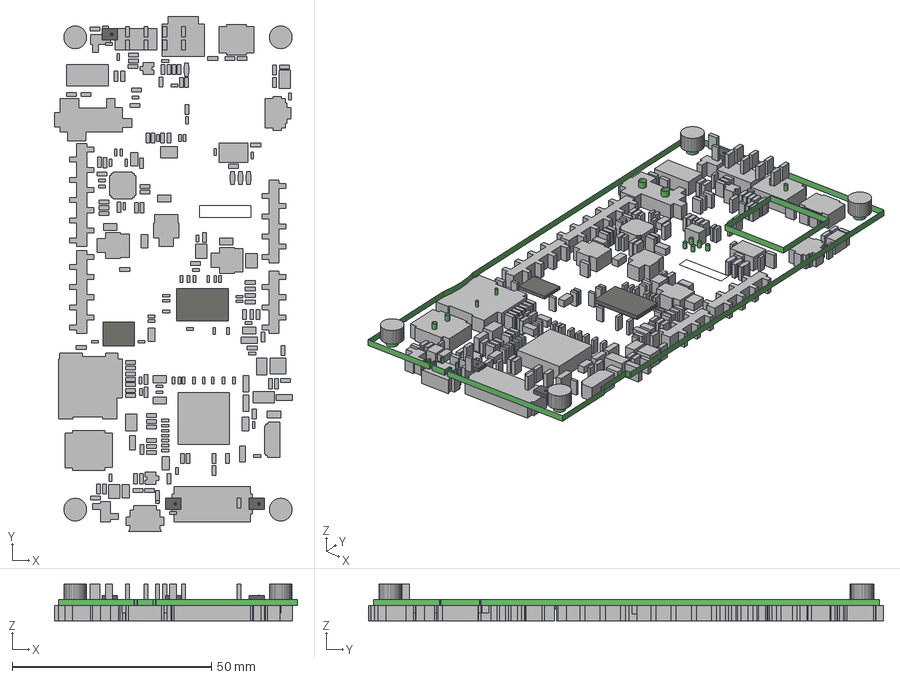
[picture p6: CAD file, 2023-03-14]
doc/MCU/en.MB1189_manufacturing/MB1189_C/Mechanical/MB1189-F469NIH6-C01.step
61.0 x 129.4 x 9.22 mm
Extruded x 233
VFBGA90-1
TAJ-A_1206_3216-8_POL x 13
TAJ-B

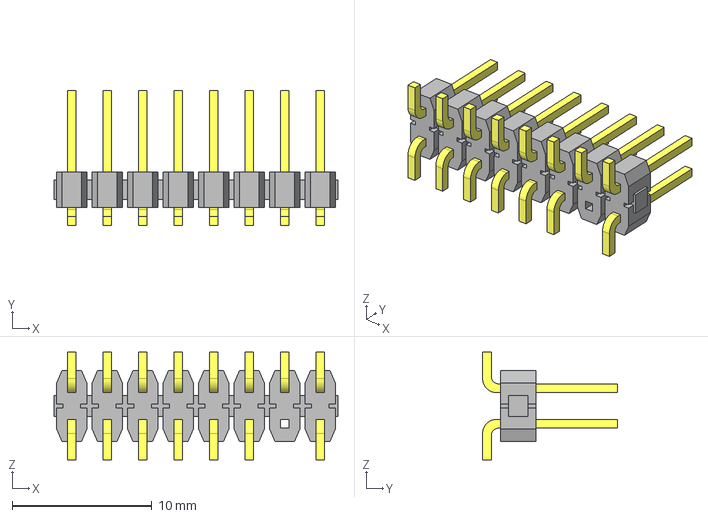
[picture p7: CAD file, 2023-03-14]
doc/MCU/en.mb1189_bdp/MB1189_C01/TSM-108-01-L-DV-014-TR.stp
20.3 x 9.65 x 7.70 mm
T-1S6-16(-01-8-DV014)
TSM-108-01-DV-014_body

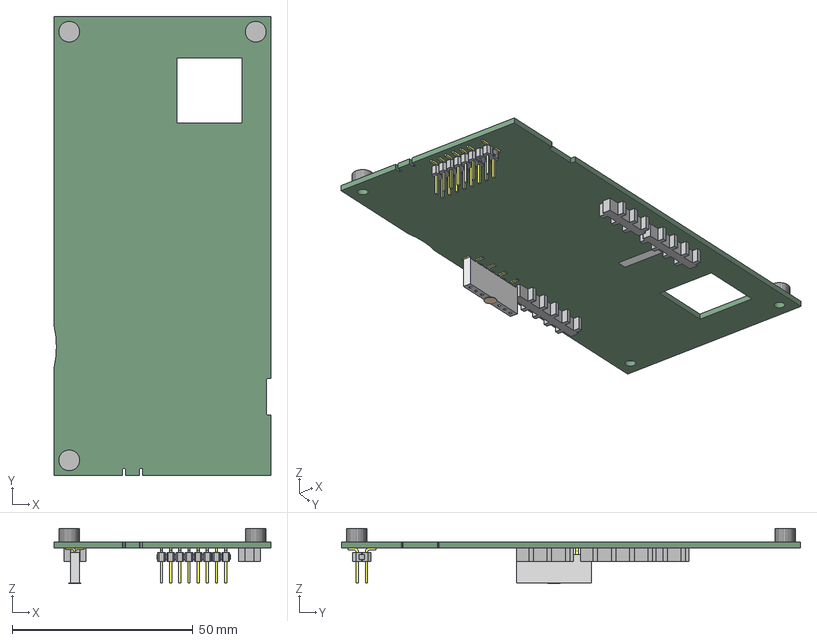
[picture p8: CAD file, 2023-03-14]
doc/MCU/en.mb1189_bdp/MB1189_C01/Copy of MB1189.step
60.0 x 127.0 x 15.3 mm
T-1S6-16(-01-8-DV014)
TSM-108-01-DV-014_body
P2SSW-108-22-G-S-VS
T1SSW-108-22-G-S-VS-K-TR
Extruded x 7

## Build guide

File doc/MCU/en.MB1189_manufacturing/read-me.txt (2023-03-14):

******************************************************************************
* @file    readme.txt
* @author  MCD Application Team
* @version 2.0
* @date    15-March-2022
* @brief   32F469IDISCOVERY bill of material package
******************************************************************************
* COPYRIGHT(c) 2020 STMicroelectronics
*
* The Open Platform License Agreement (“Agreement”) is a binding legal contract
* between you ("You") and STMicroelectronics International N.V. (“ST”), a
* company incorporated under the laws of the Netherlands acting for the purpose
* of this Agreement through its Swiss branch 39, Chemin du Champ des Filles,
* 1228 Plan-les-Ouates, Geneva, Switzerland.
*
* By using the enclosed reference designs, schematics, PC board layouts, and
* documentation, in hardcopy or CAD tool file format (collectively, the
* “Reference Material”), You are agreeing to be bound by the terms and
* conditions of this Agreement. Do not use the Reference Material until You
* have read and agreed to this Agreement terms and conditions. The use of
* the Reference Material automatically implies the acceptance of the Agreement
* terms and conditions.
*
* The complete Open Platform License Agreement can be found on www.st.com/opla.
******************************************************************************

========================
* History
========================

* 2.0 -  15-March-2022
------------------------
    + Added revision C.
    - Update the certification logos. 

* 1.0 - 13-January-2016
------------------------
    + First official release with Rev B .
	
========================
* Package content
========================

******************* (C) COPYRIGHT 2020 STMicroelectronics *****END OF FILE

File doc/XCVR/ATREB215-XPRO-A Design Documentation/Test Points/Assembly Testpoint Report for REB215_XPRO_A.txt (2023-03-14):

Net         Name        X Coord     Y Coord     Side        Hole Size   Type        
RXD09_P     J102-2        19.943mm    15.096mm  Bottom          0.75mm  Through hole
RXD09_N     J102-3        18.673mm    15.096mm  Bottom          0.75mm  Through hole
RXD24_P     J101-2        19.943mm      9.95mm  Bottom          0.75mm  Through hole
RXD24_N     J101-3        18.673mm      9.95mm  Bottom          0.75mm  Through hole
RXCLK_P     J101-5        16.133mm      9.95mm  Bottom          0.75mm  Through hole
RXCLK_N     J101-6        14.863mm      9.95mm  Bottom          0.75mm  Through hole
NetC24_1    TP8-1         30.873mm     27.91mm  Bottom             1mm  Through hole
NetJ105_2   J105-2        40.869mm     27.91mm  Bottom             1mm  Through hole
NetJ105_1   J105-1        38.329mm     27.91mm  Bottom             1mm  Through hole
NetJ104_2   J104-2        38.272mm     2.335mm  Bottom             1mm  Through hole
NetJ104_1   J104-1        40.812mm     2.335mm  Bottom             1mm  Through hole
VCC_TARGET  J100-20         2.53mm      3.57mm  Bottom             1mm  Through hole
NetJ100_18  J100-18         2.53mm      6.11mm  Bottom             1mm  Through hole
NetJ100_17  J100-17         5.07mm      6.11mm  Bottom             1mm  Through hole
NetJ100_16  J100-16         2.53mm      8.65mm  Bottom             1mm  Through hole
NetJ100_15  J100-15         5.07mm      8.65mm  Bottom             1mm  Through hole
NetJ100_9   J100-9          5.07mm     16.27mm  Bottom             1mm  Through hole
NetC6_1     J100-7          5.07mm     18.81mm  Bottom             1mm  Through hole
ID_DATA     J100-1          5.07mm     26.43mm  Bottom             1mm  Through hole
TXD_P       J103-2        19.943mm    20.192mm  Bottom          0.75mm  Through hole
TXD_N       J103-3        18.673mm    20.192mm  Bottom          0.75mm  Through hole
TXCLK_P     J103-5        16.133mm    20.192mm  Bottom          0.75mm  Through hole
TXCLK_N     J103-6        14.863mm    20.192mm  Bottom          0.75mm  Through hole
NetJ100_6   TP13-1          7.29mm    10.296mm  Bottom             0mm  Surface mount
NetJ100_5   TP12-1         8.021mm    12.172mm  Bottom             0mm  Surface mount
ID_SDA      TP11-1        19.534mm     2.074mm  Bottom             0mm  Surface mount
ID_SCL      TP10-1        19.404mm     3.933mm  Bottom             0mm  Surface mount
NetR8_1     TP4-1          13.19mm    22.526mm  Bottom             0mm  Surface mount
AVDD1       TP1-1         41.926mm      7.77mm  Bottom             0mm  Surface mount
AVDD0       TP2-1         41.471mm    19.357mm  Bottom             0mm  Surface mount
VCC_3V3     Via           33.719mm     3.763mm  Bottom          0.25mm  Through hole
GND         Via           27.481mm     6.749mm  Bottom          0.25mm  Through hole
VCC_B_3.3V  Via           41.174mm     22.65mm  Bottom          0.25mm  Through hole
NetC100_1   Via           10.875mm    25.065mm  Bottom          0.25mm  Through hole
DVDD        Via           31.094mm     9.163mm  Bottom          0.15mm  Through hole

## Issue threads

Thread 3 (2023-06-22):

Unable to program MCU via STLINK if using 5V from STLINK and J301 is closed

mdiepart, 2023-06-22:
If J301 is closed (connecting DC-DC RESET output to MCU nRESET input) then each time the embedded STLINK resets the board, the KILL signal will go low thus curring power to the board and keeping the MCU into reset.

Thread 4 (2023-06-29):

C507 not needed

mdiepart, 2023-06-29:
C507 (capacitor between the BalUn and the LPF in the Sub-GHz branch) is not needed. Furthermore it's excessively small value (0.8 pF) deteriorates the signal amplitude by about 13dB. It should be removed

sp5wwp, 2023-06-30:
Workaround - remove it and short the pads.

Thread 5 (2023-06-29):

Mounting holes too small

mdiepart, 2023-06-29:
The mounting holes are for M2.5 screws (as stated in the disco board documentation). However the board uses M3 screws, holes and spacers.
The holes should be replaced with M3 ones.

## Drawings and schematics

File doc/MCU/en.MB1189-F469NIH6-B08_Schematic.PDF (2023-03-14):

Title: Project overview

Size:

Reference:
A4 | Sheet: | of

Revision:

Project: STM32F469I-DISCO

B 08 | MB1189

F469NIH6

Date:

Variant:

Table of contents | Legend

General comment such as function title, configuration, ...

Text to be added to silkscreen.

# STM32F469I-DISCO

MB1189

Warning text.

# Open Platform License Agreement

The Open Platform License Agreement (“Agreement”) is a binding legal contract between you ("You")

and STMicroelectronics International N.V. (“ST”), a company incorporated under the laws of the

Netherlands acting for the purpose of this Agreement through its Swiss branch 39, Chemin du

Champ des Filles, 1228 Plan-les-Ouates, Geneva, Switzerland.

By using the enclosed reference designs, schematics, PC board layouts, and documentation, in hardcopy

or CAD tool file format (collectively, the “Reference Material”), You are agreeing to be bound by

the terms and conditions of this Agreement. Do not use the Reference Material until You have read

and agreed to this Agreement terms and conditions. The use of the Reference Material automatically

implies the acceptance of the Agreement terms and conditions.

The complete Open Platform License Agreement can be found on www.st.com/opla.

U_Top
Top.SchDoc

Sheet 1: Project overview (this page)

Sheet 2: Top

Sheet 13: ST-LINK/V2-1

Sheet 3: STM32 microcontroller

Sheet 8: 4 inch DSI LCD board

Sheet 7: Audio Codec and Microphone MEMS

Sheet 5: Power

Sheet 9: SDRAM

Sheet 11: USB_OTG_FS

Sheet 10: QSPI

Sheet 6: Peripherals

Sheet 12: Arduino Uno connector

Sheet 4: Extension Connectors | Notes to generate the
| board layout.

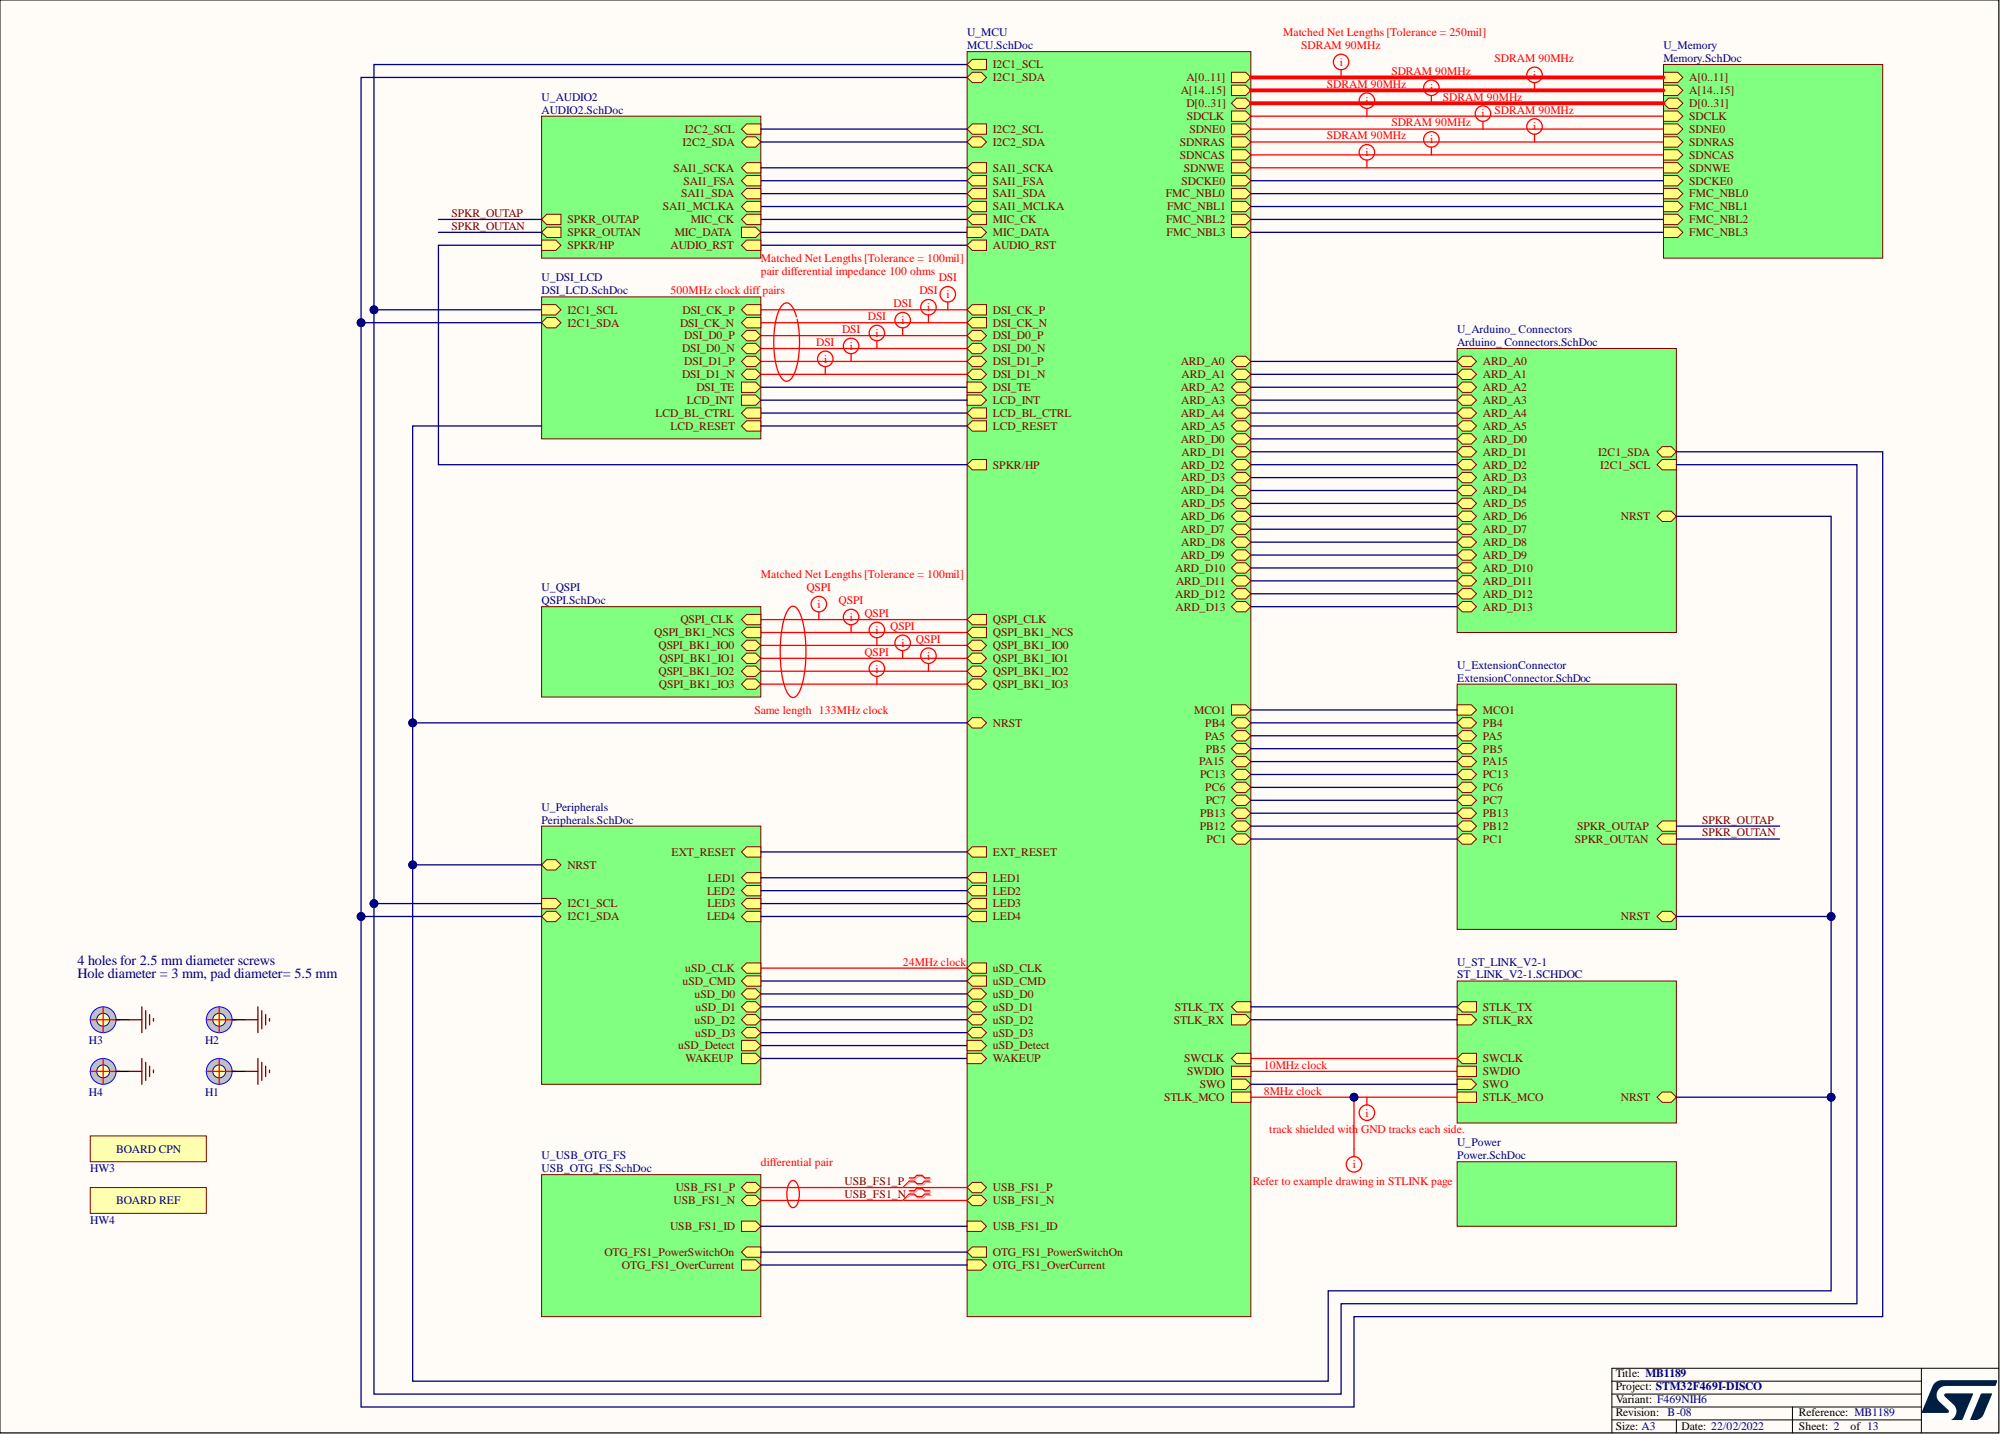
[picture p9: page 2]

Matched Net Lengths [Tolerance = 250mil]
SDRAM 90MHz

U_AUDIO2 AUDIO2.SchDoc

i SDRAM 90MHz

Matched Net Lengths [Tolerance = 100mil]
pair differential impedance 100 ohms

I2C1_SDA DSI_CK_N | DSI i

DSI_D0_P DSI_D0_N DSI_D1_P DSI_D1_N DSI_TE LCD_INT LCD_BL_CTRL LCD_RESET | DSI

DSI

4 holes for 2.5 mm diameter screws
Hole diameter = 3 mm, pad diameter= 5.5 mm

track shielded with GND tracks each side.

Refer to example drawing in STLINK page

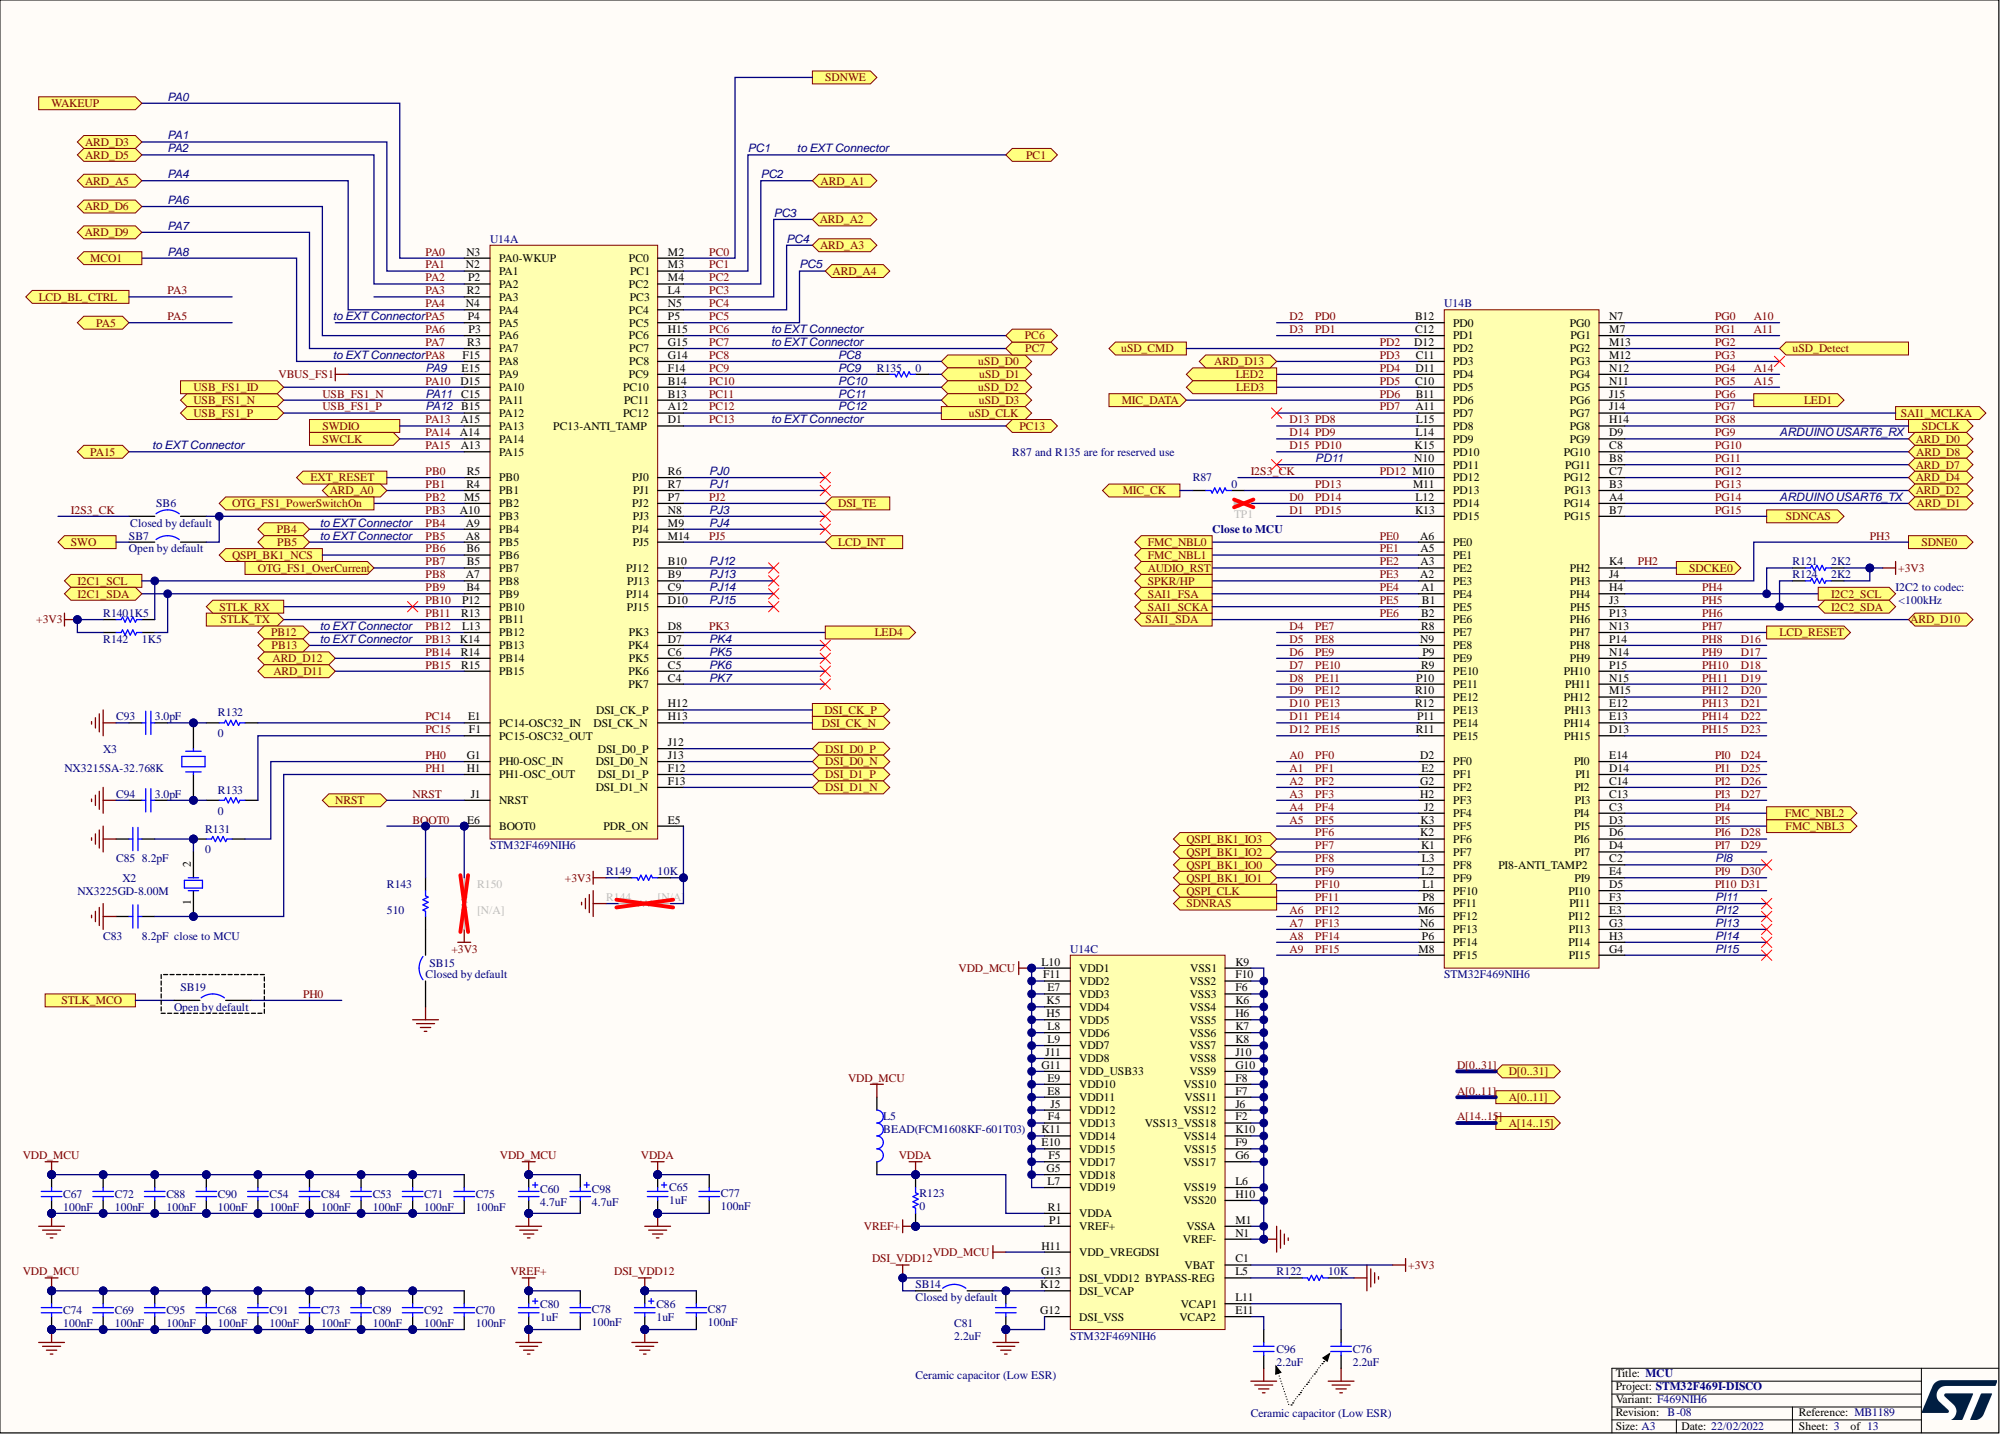
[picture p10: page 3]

PA1 | PA1 N2 | PC1 PC5
PA2 | PA2 P2 | PC2

R87 and R135 are for reserved use

Ceramic capacitor (Low ESR)

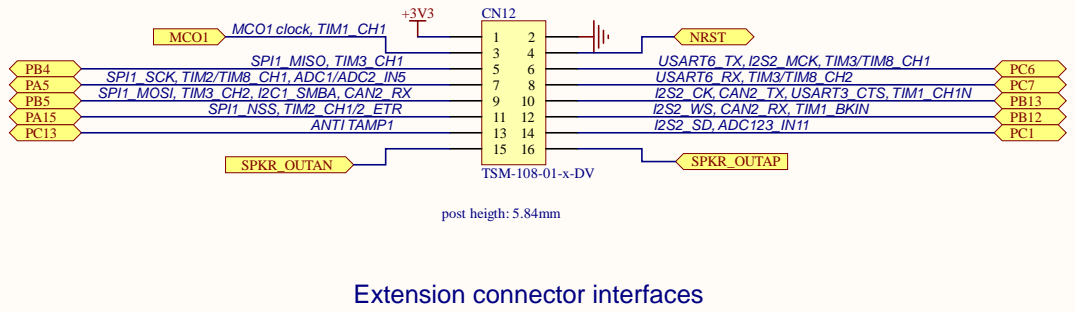
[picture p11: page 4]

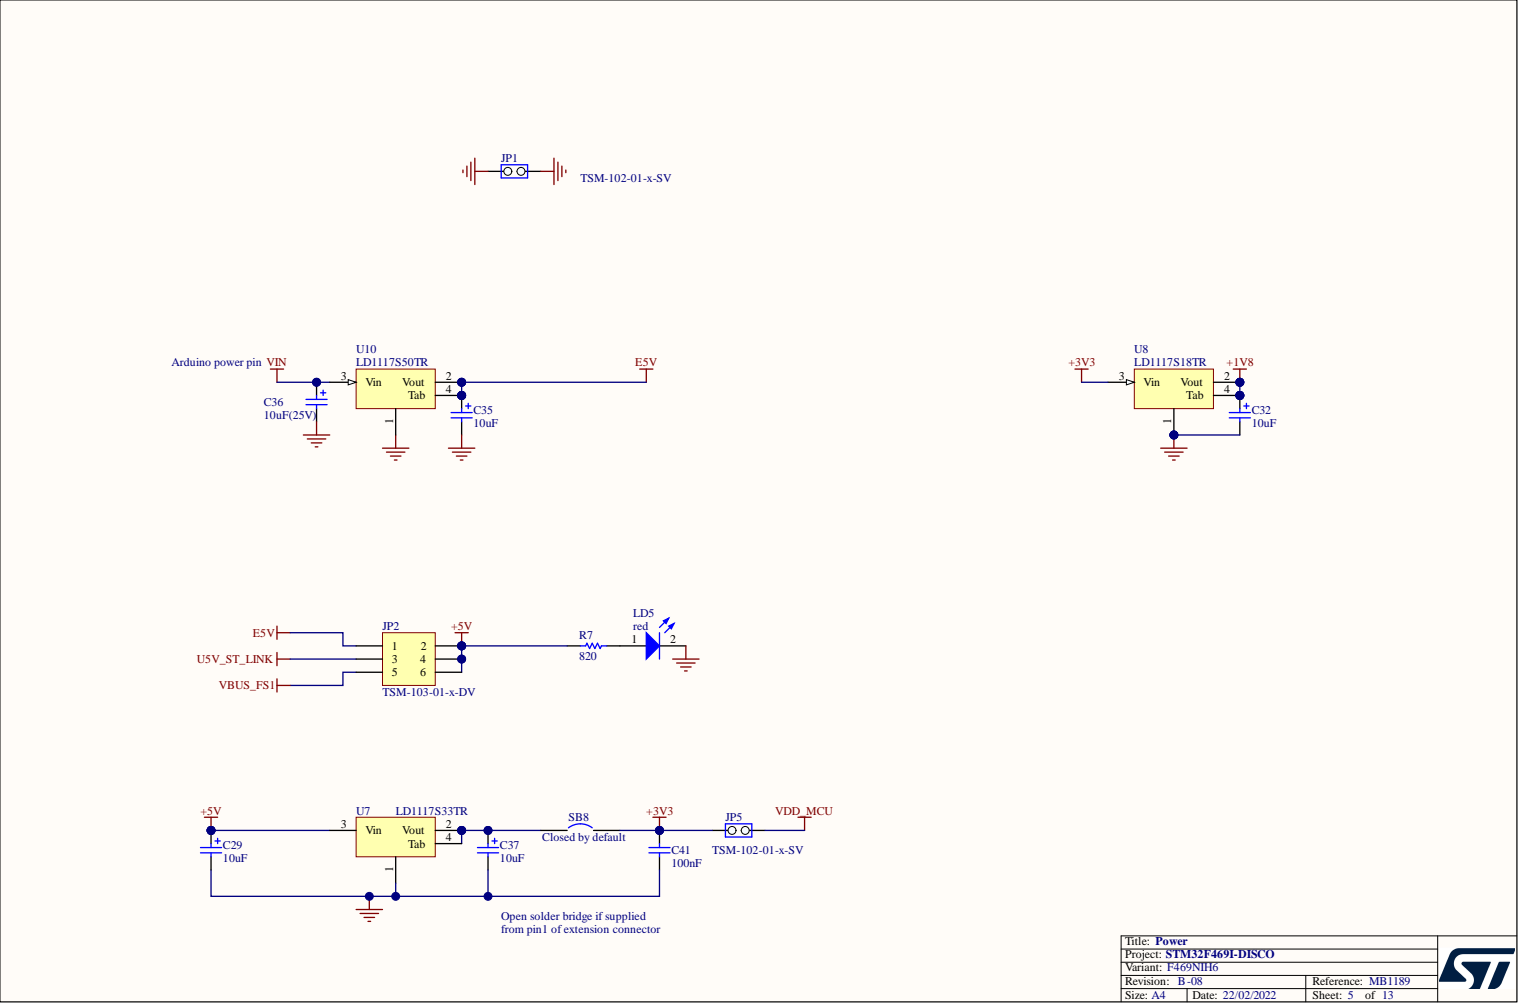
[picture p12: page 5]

Open solder bridge if supplied
from pin1 of extension connector

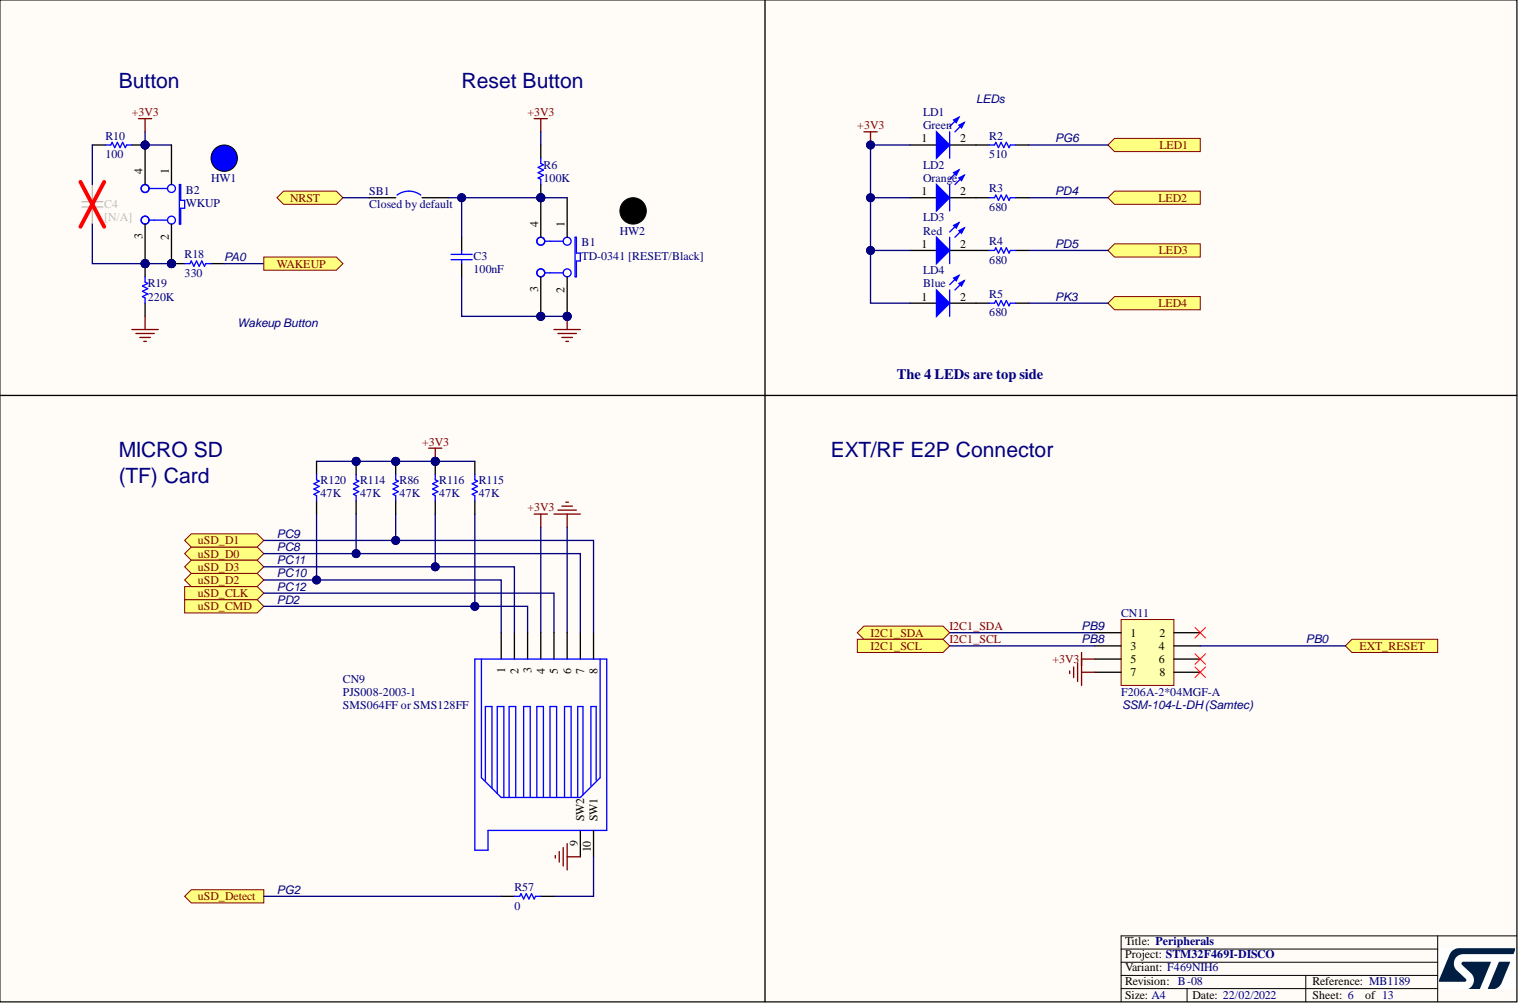
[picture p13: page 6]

The 4 LEDs are top side

PC8
PC11
PC10
PC12
PD2

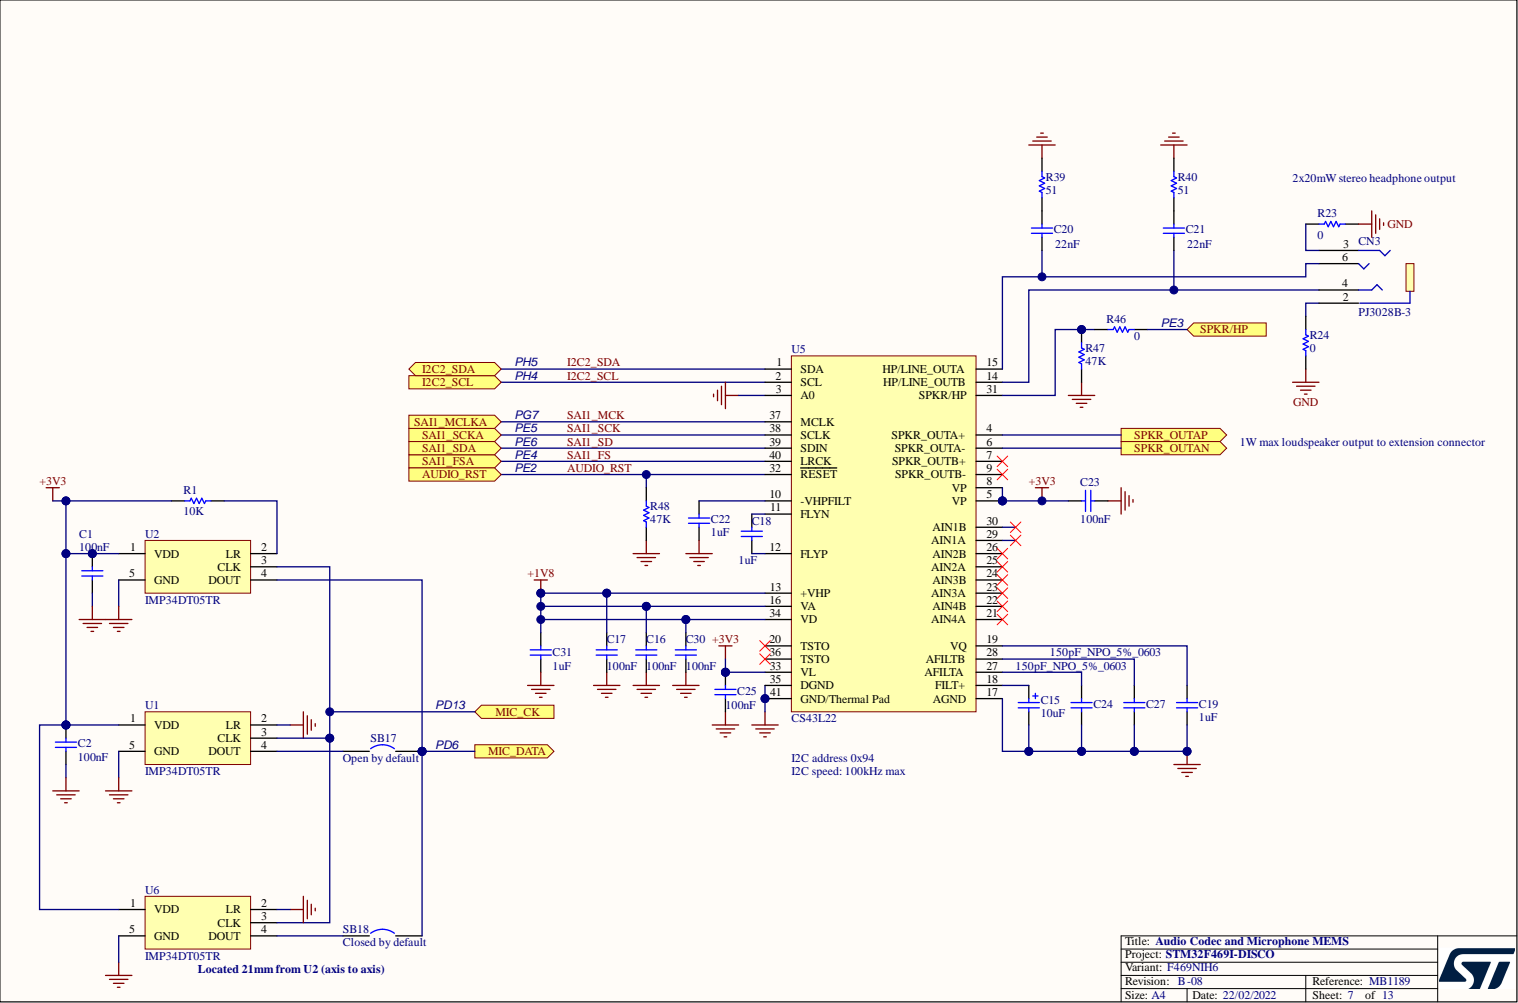
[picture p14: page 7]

1W max loudspeaker output to extension connector

TSTO 36 | 150pF_NPO_5%_0603
VL 33 | 150pF_NPO_5%_0603

Title: Audio Codec and Microphone MEMS

Located 21mm from U2 (axis to axis)

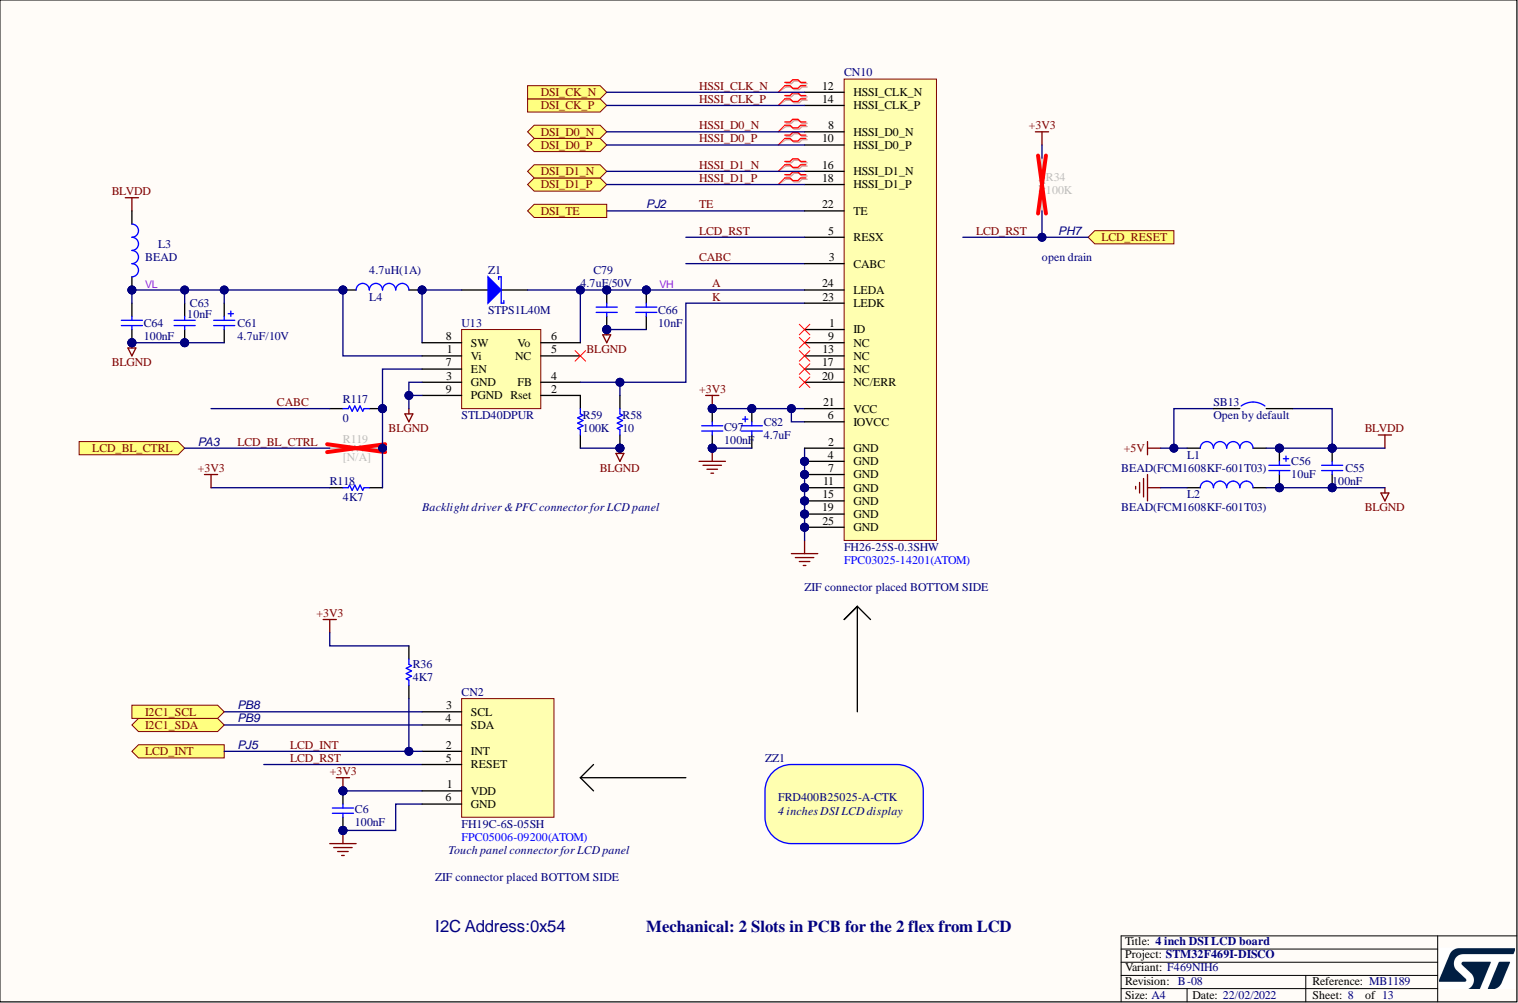
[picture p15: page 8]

Backlight driver &PFC connector for LCD panel

ZIF connector placed BOTTOM SIDE

FRD400B25025-A-CTK
4 inches DSI LCD display

FPC05006-09200(ATOM)
Touch panel connector for LCD panel

Mechanical: 2 Slots in PCB for the 2 flex from LCD

Title: 4 inch DSI LCD board

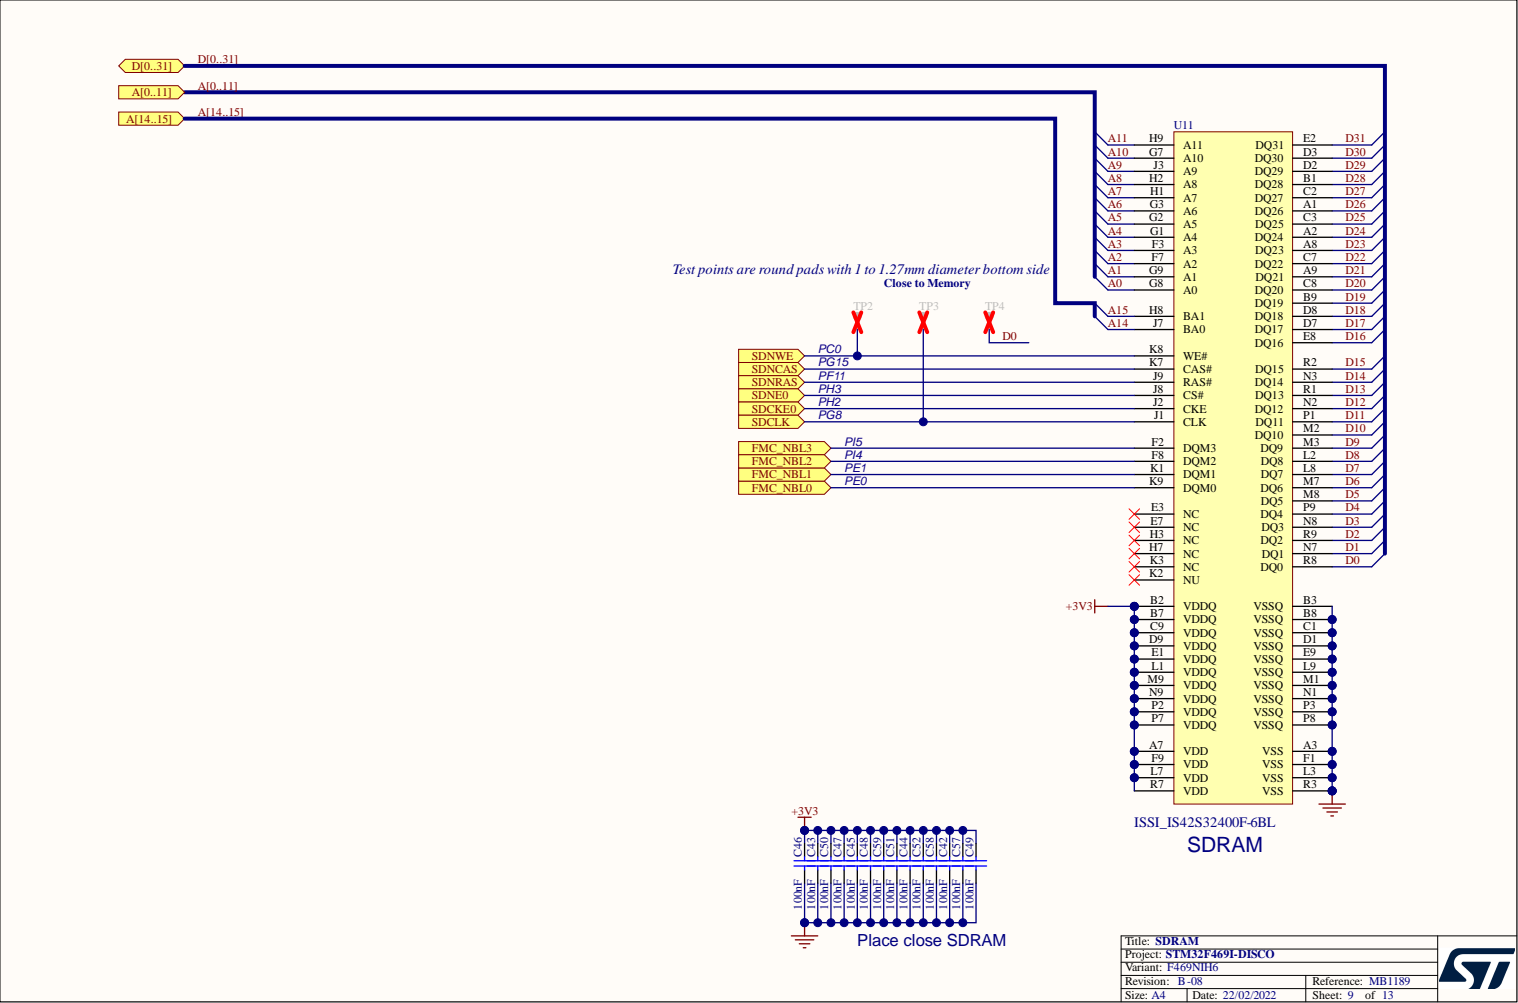
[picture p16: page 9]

D 9 | D 1
E 1 | E 9
L 1 | L 9

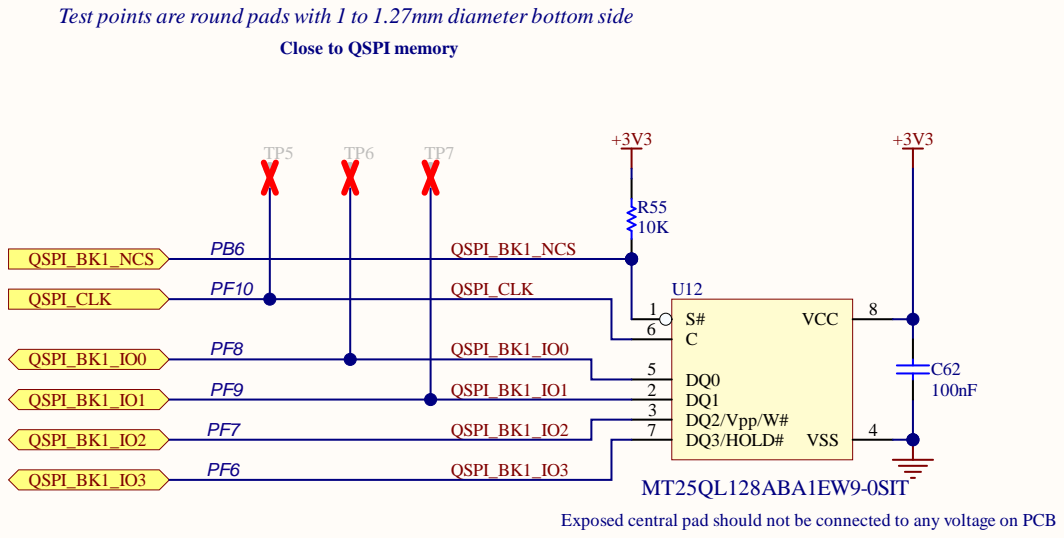
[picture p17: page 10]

QSPI _BK 1 _ I O 0

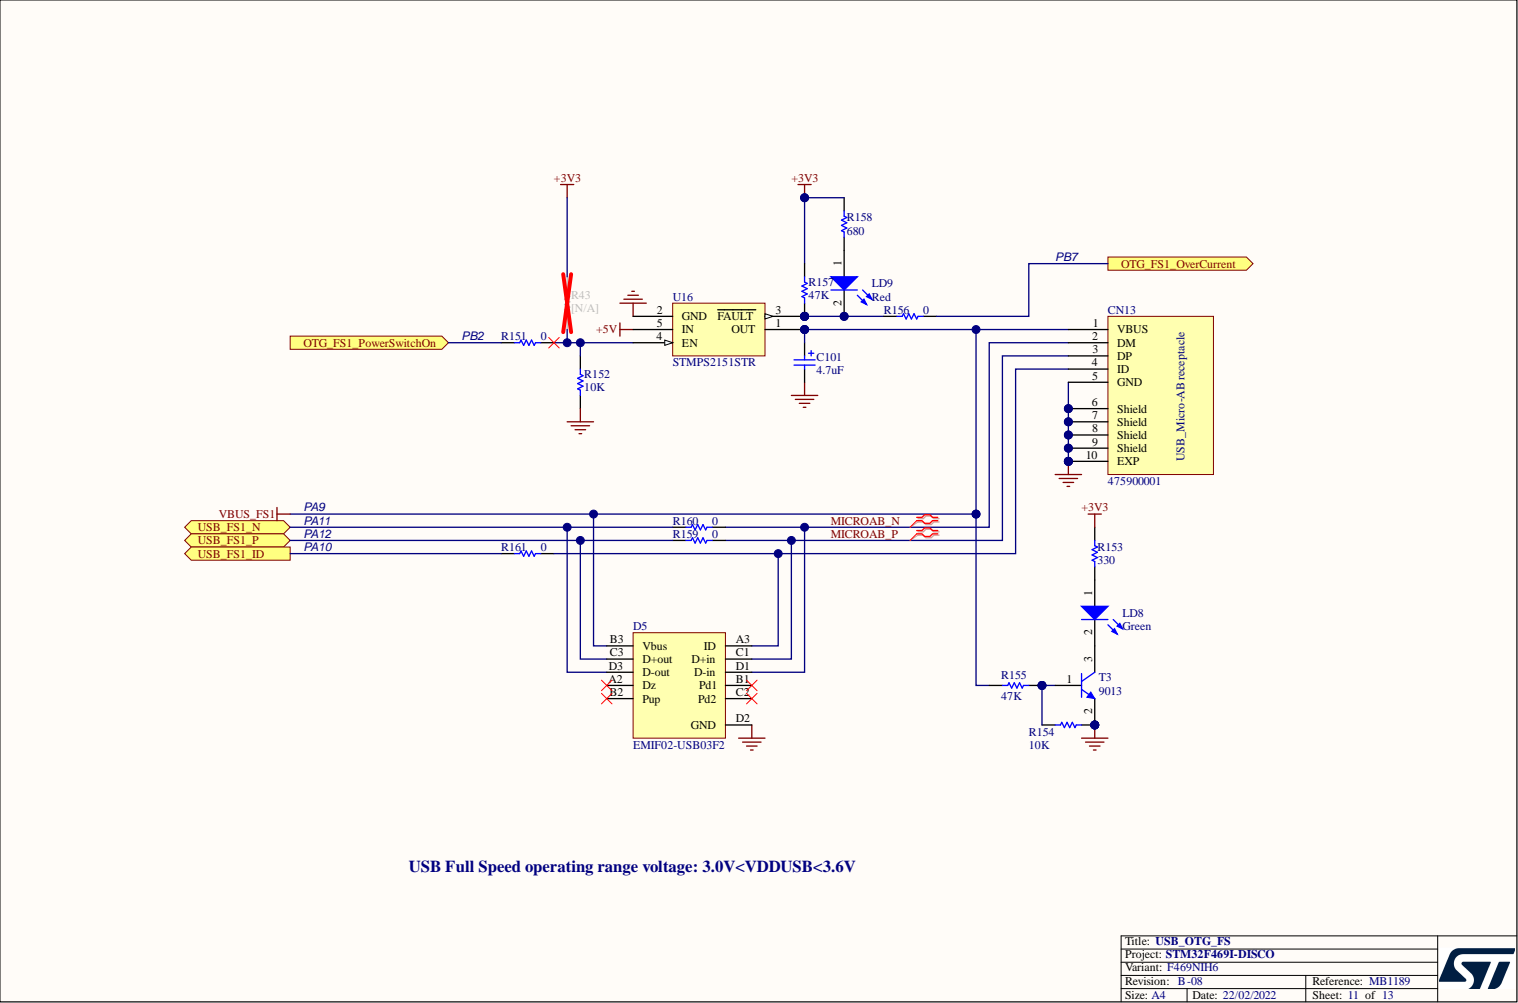
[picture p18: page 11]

R152 10K | GND 5

USB Full Speed operating range voltage: 3.0V<VDDUSB<3.6V

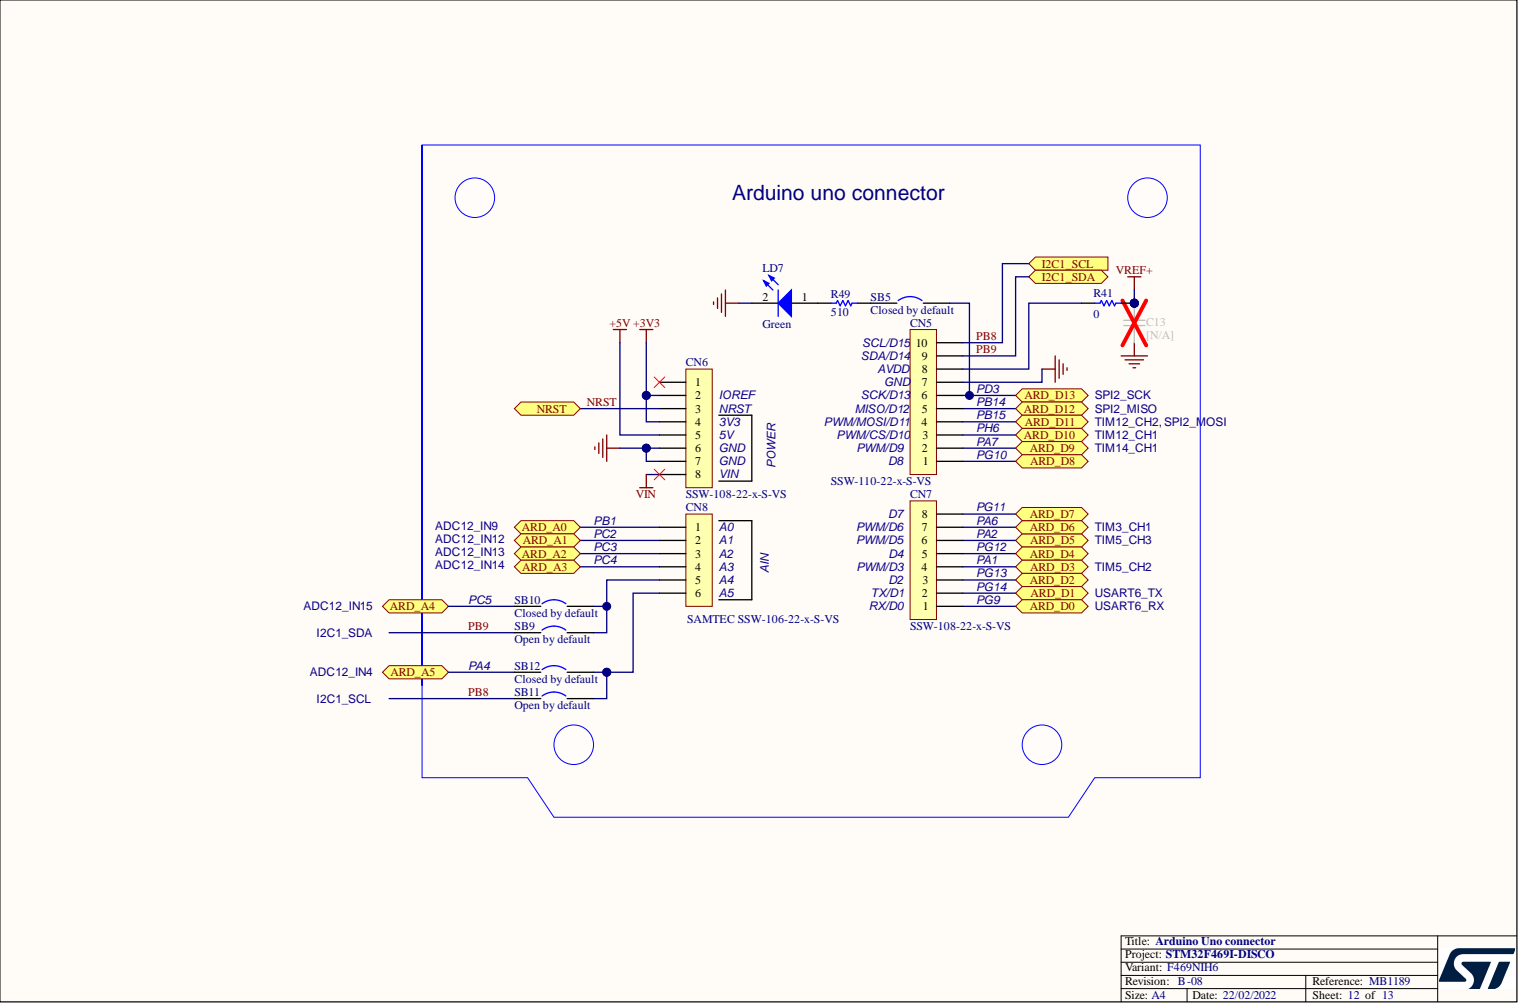
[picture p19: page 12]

Title: Arduino Uno connector

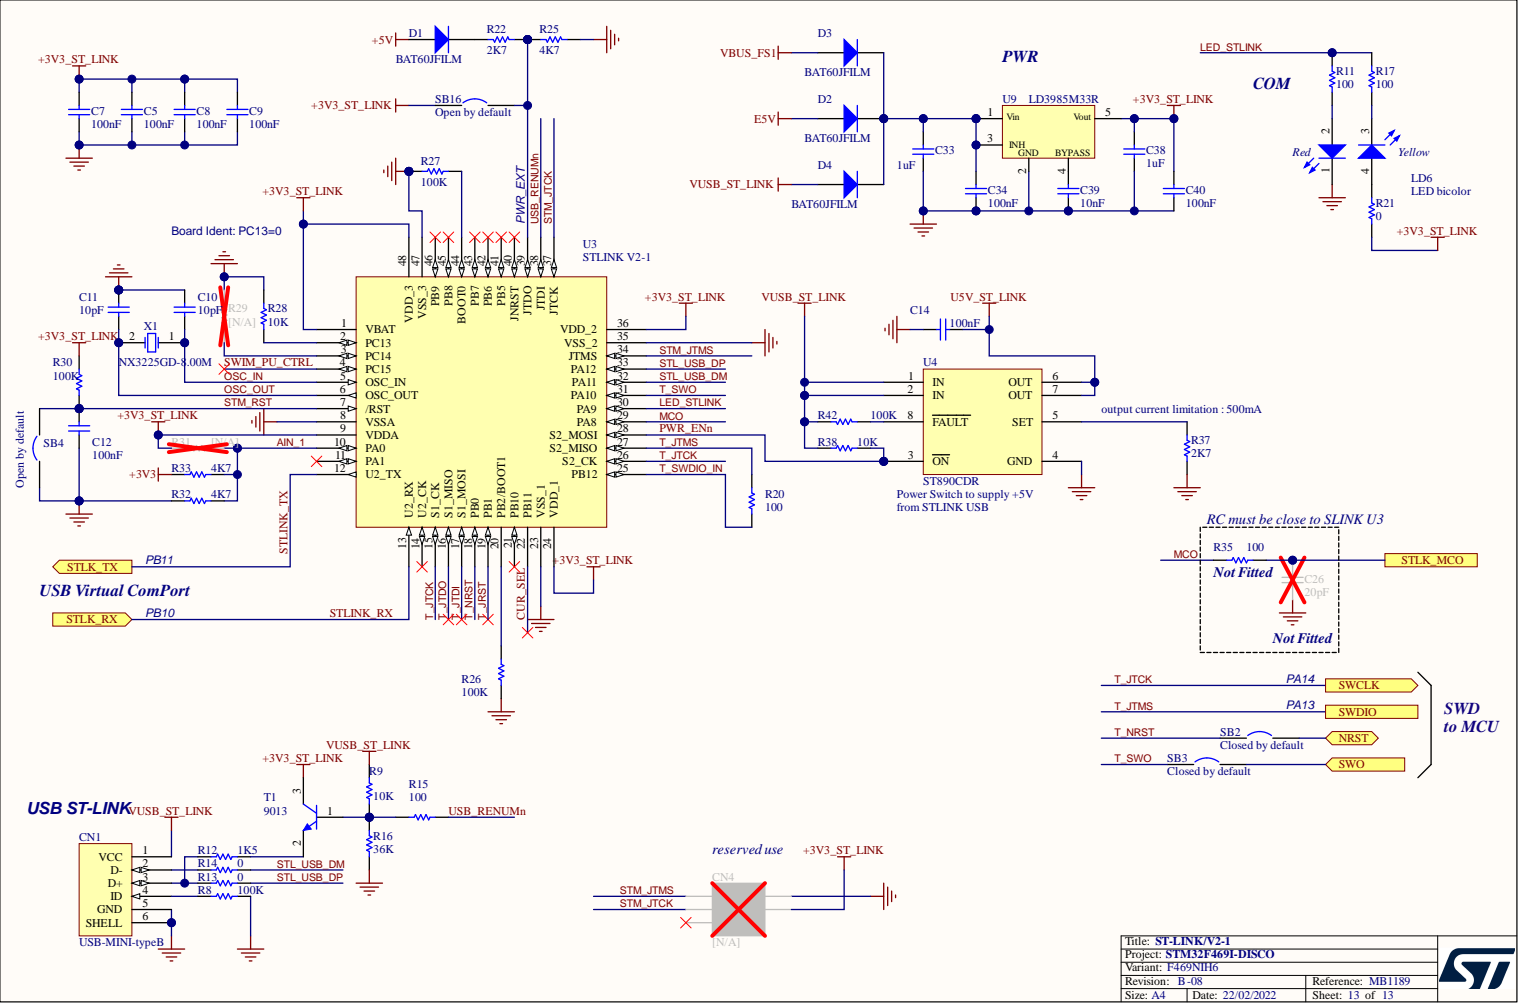
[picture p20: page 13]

JTCK 37 JTDI 38 JTDO 39 JNRST 40 PB5 41 PB6 42 PB7 43 BOOT0 44 PB8 45 PB9 46 VSS_3 47 VDD_3 48

VSSA 8

R31 [N/A] AIN_1 | | PA0 10 | T_JTMS

100nF | R33 4K7 | | | PA1 11 | T_JTCK T_SWDIO_IN

ST890CDR
Power Switch to supply +5V
from STLINK USB

RC must be close to SLINK U3

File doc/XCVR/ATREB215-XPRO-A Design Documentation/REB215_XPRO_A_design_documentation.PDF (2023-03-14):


Kandanchavadi | * *

Chennai


Standard Extension Header (Female)

[DESIGN NOTE]
The ATSHA204 is powered through an IO Pin
from the EDBG on an MCU board.
R100 is present to drain the capacitor C100 when
power is removed from an MCU board.

4 3

5 | FEM 24


Power and RF Status LEDs

RESET button with current limit and noise filter

100K | TCXO 17 QFN48 U1 | RF24_N

DVDD 37

Kandanchavadi | *

Chennai









Fitted | Designator | Quantity MPN | | Manufacturer | Value | Description | Comment
Fitted | B1 | 1 | 2450FB15A050 | Johanson Technology | 2450FB15A050 | 2.45 GHz Balun / Filter Combination | Balun_2.4GHz
Fitted | B2 | 1 | 0896BM15E0025E | Johanson Technology | 0896BM15E0025E | 863/915 MHz ISM band Balun+LPF for AT86RF215 | Balun_2.4GHz
Fitted | C1, C9, C11, C13, C14, C15, C16, C17 | 8 C0402C104K4RACTU | | Kemet | 100n | Ceramic capacitor, SMD 0402, X7R, 16V, +/-10% | CAP-NONPOL
Fitted | C2, C12 | 2 250R05L1R8BT4T | | Johanson Technology | 1.8pF | CAP CER 1.8PF 25V NP0 0201 | CAP-NONPOL
Fitted | C3 | 1 | 250R05L0R8AV4T | Johanson Technology | 0.8pF | CAP CER 0.8PF 25V NP0 0201 | CAP-NONPOL
Fitted | C6 | 1 | | | 4.7n | Ceramic capacitor, SMD 0402, X7R, 25V, +/-10% (de35287) | CAP-NONPOL
Fitted | C8 | 1 | GRM0335C1E150JA01 D | Murata | 15pF | CAP CER 15PF 25V NP0 0201 | CAP-NONPOL
Fitted | C10 | 1 | C0603C0G1E100C | tdk | 10pF | CAP CER 10PF 25V Â±.25pf ( and Â±.30ppm/ degree C of temp variation) NP0 0201 | High Temp version
Fitted | C18, C19, C20 | 3 C0402C105K9PAC | | Kemet | 1u | Ceramic capacitor, SMD 0402, X5R, 6.3V, +/-10% (de26942) | CAP-NONPOL
Fitted | C23 | 1 | GRM319R60J106KE19 | Murata | 10u | Ceramic capacitor, SMD 1206, X5R, 6.3V, ±10% | CAP-NONPOL
Fitted | C24 | 1 | GRM1555C1H2R2CZ01 D | Murata | 2.2pF | Ceramic capacitor, SMD 0402, NP0, 50V, +/-0.25pF (de23847) | CAP-NONPOL
Fitted | C25 | 1 | 100R05W102KV4 | Johanson Technology | 1nF | Ceramic capacitor, SMD 0201, X7R, 10V, +/-10% | Alternate PN GRM033R71C102KA01D is good, but for Rated Voltage
Fitted | C100, C101 | 2 GRM155R60J475ME87 | D | Murata | 4.7uF | Ceramic capacitor, SMD 0402, X5R, 6.3V, +/-20% (de33687) | Recommended by Escatec. No datasheet available yet.
Fitted | D1 | 1 | EL17-21SYGC | Everlight | EL17-21SYGC | LED, Green, Wave length=575nm, SMD 0805, ±70° | LED_12
Fitted | D2 | 1 | 17-21UYC/S530-A3/TR8 | Everlight | EL17-21UYC/A3 | LED, Yellow, Wave length=591nm, SMD 0805, ±70° | LED_12
Fitted | E1, E2, E3 | 3 SJ-5076 | | 3M | SJ-5076 | 2.8mm adhesive feet,diam 8.0mm | RUBBER FEET
Fitted | J1, J104, J105 | 3 HMTSW-102-23-F-S- | 237 | SAMTEC | HMTSW-102-23-F-S-237 | 1x2 pin header, 2.54mm pitch, Pin-in-Paste THM | HEADER 1x2
Fitted | J100 | 1 | F201-2*10RGF-W2-NF | Pro-data International Corp | F201-2*10RGF-W2-NF | 2x10, female pin header receptable, right-angled, 2.54mm pitch, THM, Pin In Paste | HEADER-2X10
Fitted | J101, J102, J103 | 3 67491-1030 | | Molex | 67491-1030 | 1.27mm Pitch Serial ATA High Speed Header, Through Hole, Vertical, 7 Circuits | SATA_7PIN_HEADER
Fitted | JS1 | 1 | SNT-100-BK-G | SAMTEC | SNT-100-BK-G | Jumper cap for 2.54mm pinheader | To be used by request from ESCATEC
Fitted | L2 | 1 | 74279263 | Wurth Elektronik | 74279263 | SMD-Ferrite 220Ohm, 100MHz 0603 size, (de14411) | Inductor_Iron
Fitted | L3 | 1 | L-05B5N6SV6T | Johanson Technology | 5.6nH | ceramic chip inductor, 5.6nH, 0201 | ceramic chip inductor, 5.6nH, 0201
Fitted | LABEL1 | 1 | 505462 | ACT Logimark AS | 505462 | Label for use on wireless PCBA that needs IC ID and FCC ID | Label PCBA with IC ID and FCC ID
Fitted | P1 | 1 | U.FL-R-SMT-1(10) | HIROSE | U.FL-R-SMT-1(10) | UFL (Small Coax Connector) | Copy of A08-0629
Fitted | Q1 | 1 | 2N7002DW | Fairchild | 2N7002DW | Dual N-Channel MOSFET, 60V, 115mA cont,RDS(ON) < 7.5 Ohm @50mA@5V, SOT-363 | Same as 2N7002 but with two MOSFETs in one package
Fitted | R1, R5 | 2 | | | 1M | Thick film resistor, SMD 0402, 1/16W, 1% | R2
Fitted | R2, R3 | 2 | | | 330R | Thick film resistor, SMD 0402, 1/16W, 1% | R2
Fitted | R4, R9 | 2 MCR006YZPJ000 | | ROHM | 0R | Thick film resistor, SMD 0201, 1/20W, 5% | Copy of A02-0534
Fitted | R6, R100 | 2 | | | 100k | Thick film resistor, SMD 0402, 1/16W, 1% | R2
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

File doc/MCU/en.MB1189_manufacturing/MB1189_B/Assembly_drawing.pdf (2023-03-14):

# www.st.com/stm32f4-discovery VBUS


# JP1R151

R20R18


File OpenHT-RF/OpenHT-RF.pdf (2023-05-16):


RF_RST SW_CTL1 SW_CTL2 PTT Connectors File: conn.kicad_sch

PB_INT MAIN_KILL PWR_RESET Power supply File: pwr.kicad_sch

Id: 1/5 Title: OpenHT - open source SDR handheld


PWR_EN Open this jumper to disable UVLO

47nF X5R or better 10V or higher U202C

2 EN 3 ADJ 4 V_{out}5 U203 AP7330-W5-7 GND

4 EN/UVLO 5 VIN 6 U204 TPS22810DBVR GND GND

Id: 2/5 Title: OpenHT - open source SDR handheld


Id: 3/5 Title: OpenHT - open source SDR handheld


If needed, IO4,
IO5, IO6 can be
used as SPI bus (SPI2 on

If pulled high,
the SPI pins will be reconfigured

Id: 4/5 Title: OpenHT - open source SDR handheld


3 RXDN09 30 RXDP09 31 DVSS 32 RXCLKN 33 RXCLKP 34 RXDN24 35 RXDP24 36 DVDD 37 DVSS 38 DEVDD 39 RFP24 4

J501 EMPCB.CSMAFSTJ.A GND GND GND

DVSS and AVSS should be
layer. Do not connect DVSS to

Id: 5/5 Title: OpenHT - open source SDR handheld














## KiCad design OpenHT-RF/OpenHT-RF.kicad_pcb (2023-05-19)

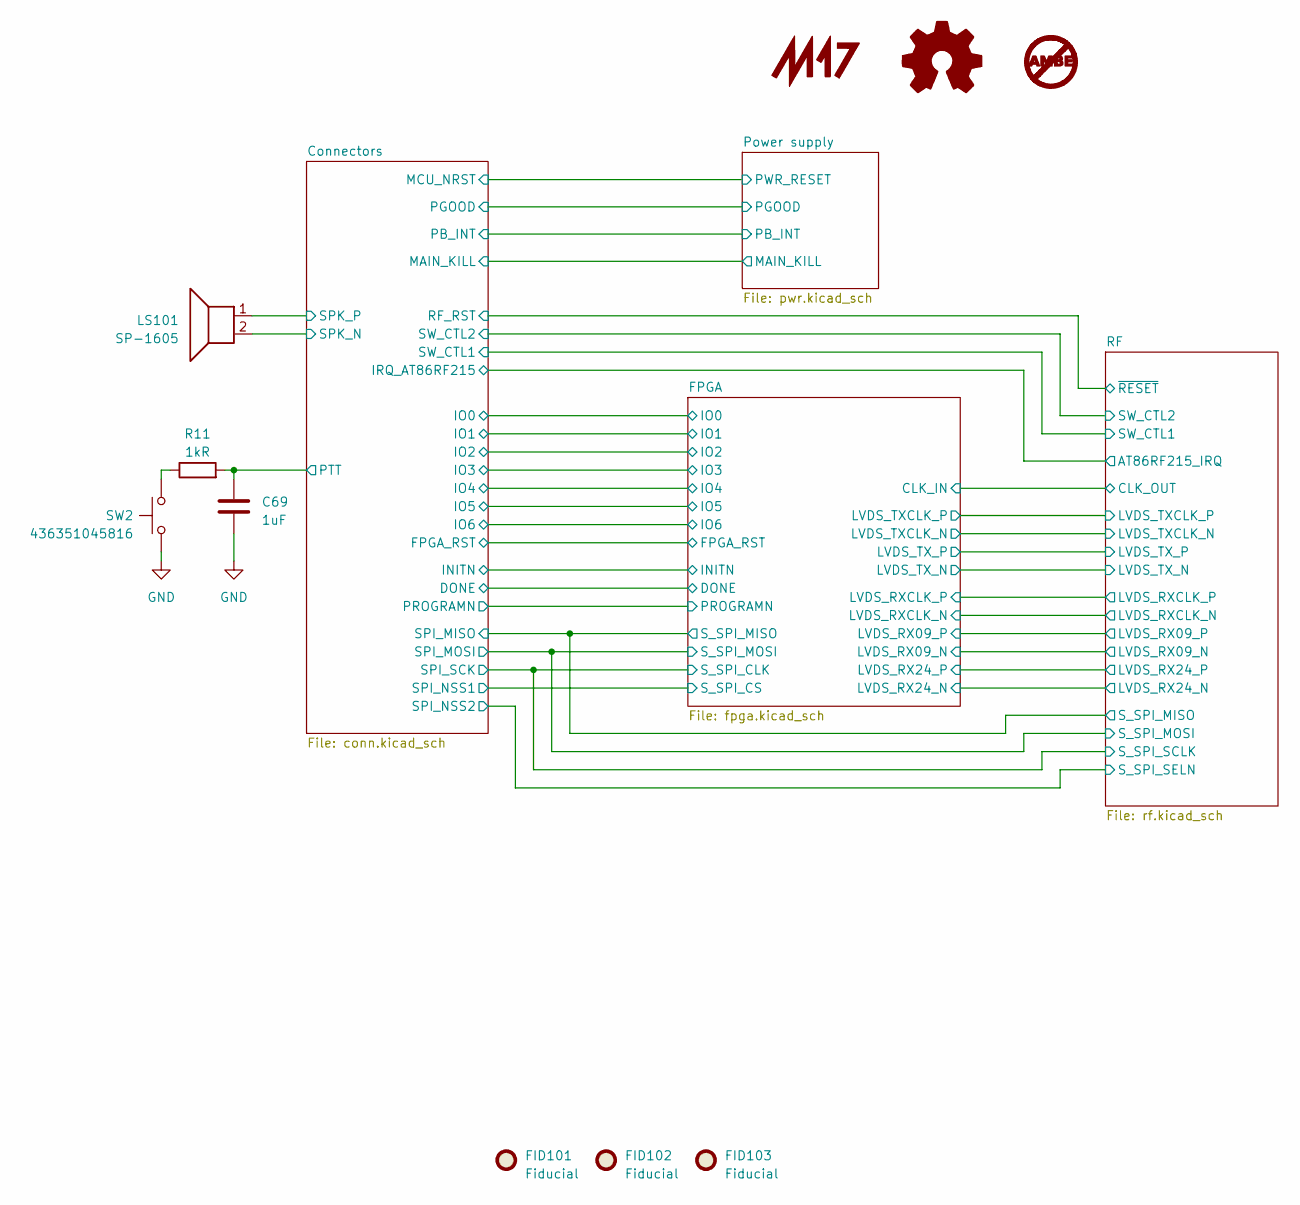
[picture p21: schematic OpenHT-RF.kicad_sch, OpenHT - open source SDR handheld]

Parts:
C69: 1uF; C_0402_1005Metric; MPN Generic C/1uF/0402/X5R/10V
FID101, FID102, FID103: Fiducial; Fiducial_1mm_Mask2mm
LOGO101: M17_logo_20mmx15mm
LS101: SP-1605; Pin_1x02_P2.54mm_horizontal_SMD; MPN SP-1605
R11: 1kR; R_0402_1005Metric; Tolerance 1%; MPN Generic R/1kR/0402/1%
SW2: 436351045816; SW_SPST_436351045816; MPN 436351045816
SYM101: Logo_Open_Hardware_Small; OSHW-Logo_7.5x8mm_SilkScreen

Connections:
/Connectors/SPK_N: LS101.2; also elsewhere on the board
/Connectors/SPK_P: LS101.1; also elsewhere on the board

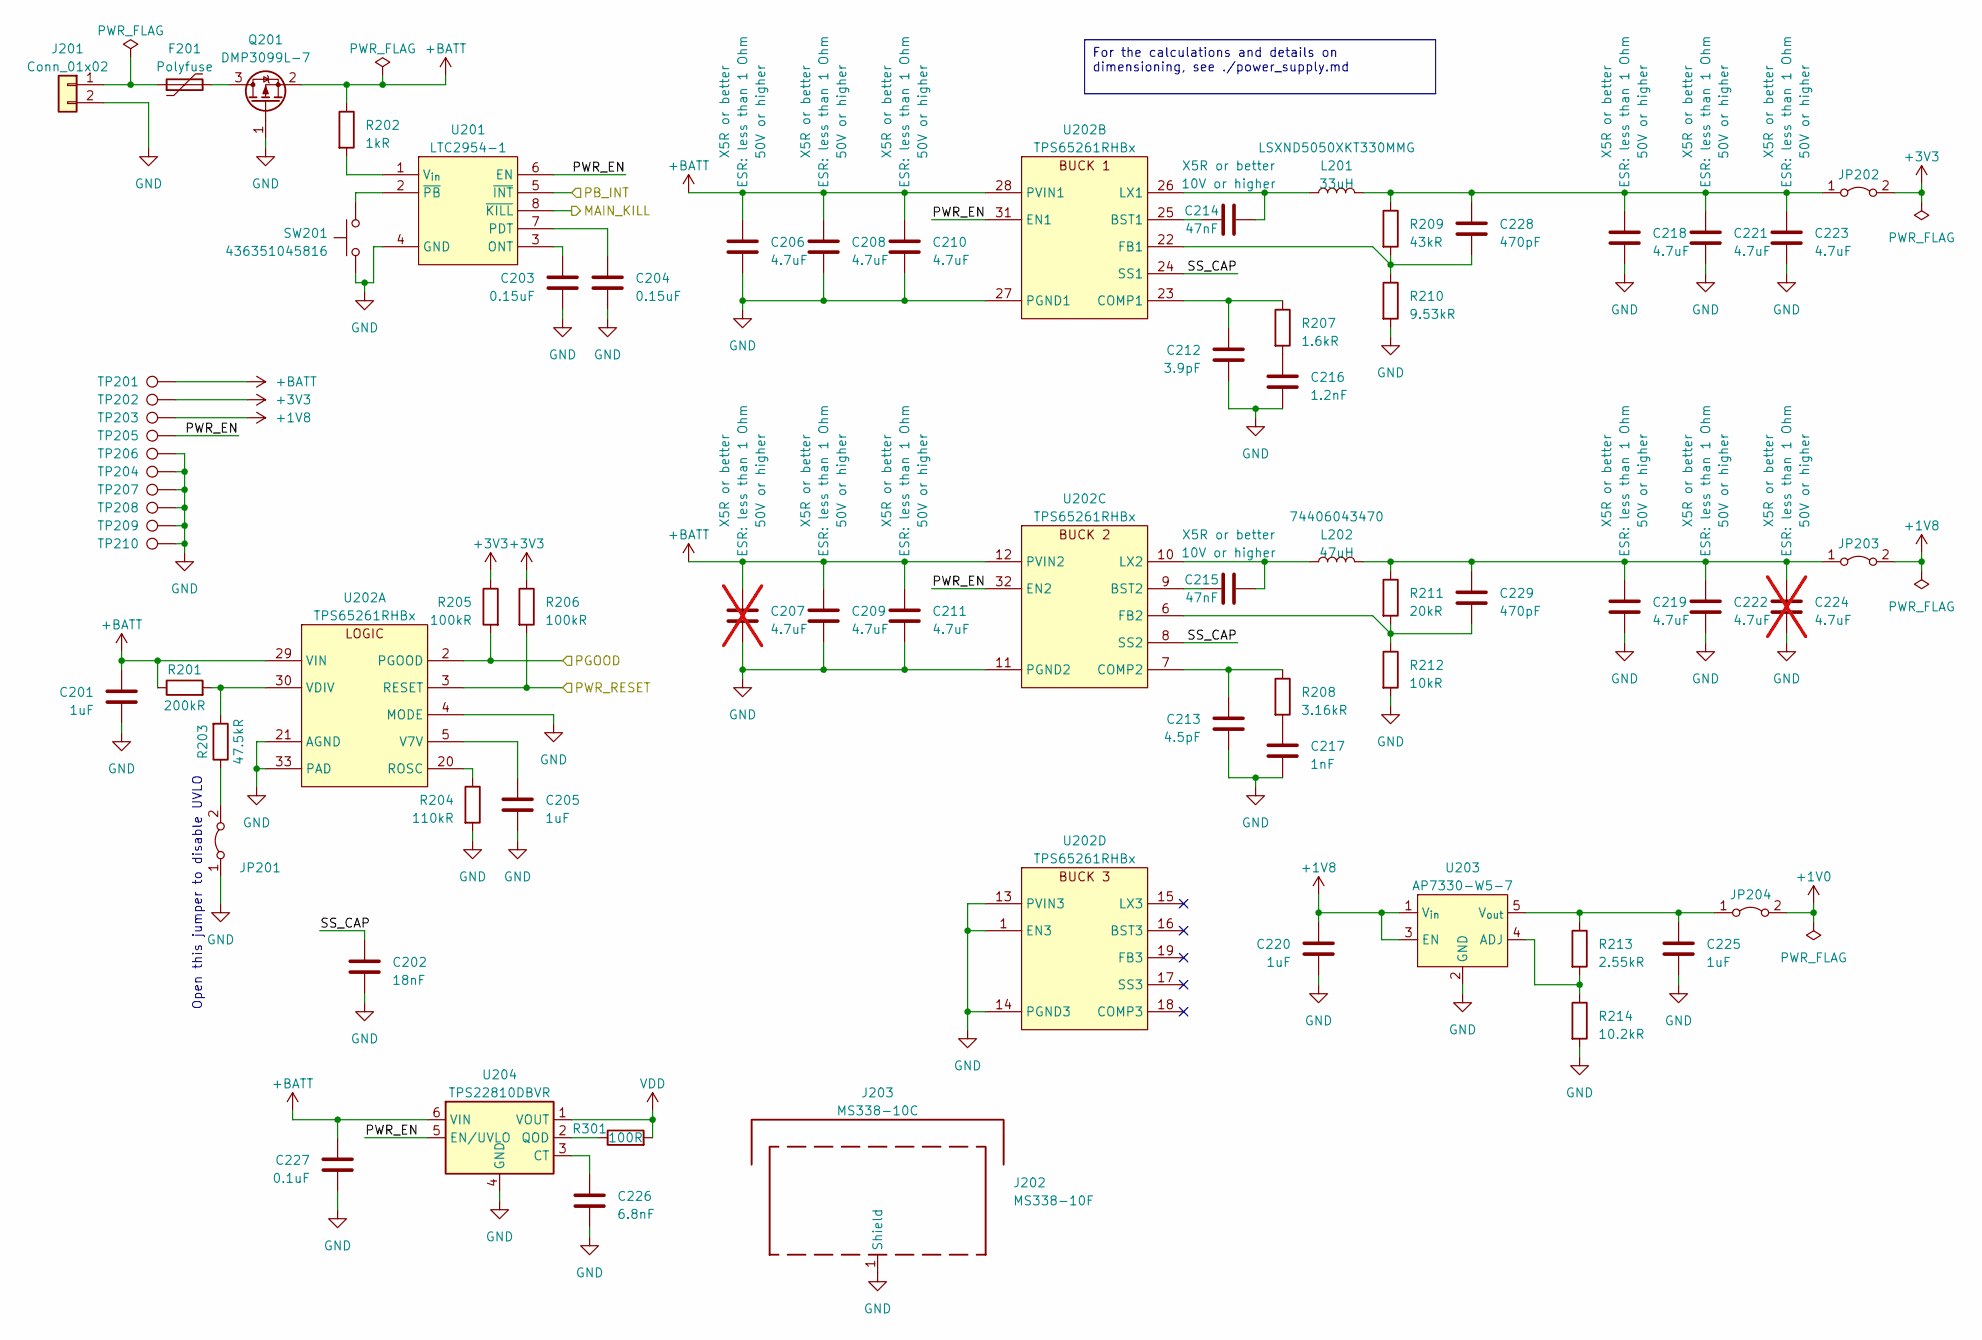
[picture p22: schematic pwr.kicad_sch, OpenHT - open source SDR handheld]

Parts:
C201, C205, C220, C225: 1uF; C_0402_1005Metric; MPN Generic C/1uF/0402/X5R/10V
C202: 18nF; C_0402_1005Metric; MPN Generic C/18nF/0402/X7R/10V
C203, C204: 0.15uF; C_0402_1005Metric; MPN Generic C/0.15uF/0402/X5R/10V
C206, C208, C209, C210, C211, C218, C219, C221, C222, C223: 4.7uF; C_0805_2012Metric; Rated voltage 50V or higher; MPN Generic C/4.7uF/0805/X5R/25V
C207, C224: 4.7uF; C_0805_2012Metric; Rated voltage 50V or higher; MPN Generic C/4.7uF/0805/X5R/25V; not fitted
C212: 3.9pF; C_0402_1005Metric; MPN Generic C/3.9pF/0402/C0G/10V
C213: 4.5pF; C_0402_1005Metric; MPN Generic C/4.5pF/0402/C0G/10V
C214, C215: 47nF; C_0402_1005Metric; Voltage 10V or higher; MPN Generic C/47nF/0402/X5R/10V
C216: 1.2nF; C_0402_1005Metric; MPN Generic C/1.2nF/0402/X7R/10V
C217: 1nF; C_0402_1005Metric; MPN Generic C/1nF/0402/X7R/10V
C226: 6.8nF; C_0402_1005Metric; MPN Generic C/6.8nF/0402/X5R/10V
C227: 0.1uF; C_0402_1005Metric; MPN Generic C/0.1uF/0402/X7R/16V
C228, C229: 470pF; C_0402_1005Metric; MPN Generic C/470pF/0402/X7R/16V
F201: Polyfuse; Fuse_1812_4532Metric; MPN SMD1812B200TF/16
J201: Conn_01x02; TerminalBlock_4Ucon_1x02_P3.50mm_Horizontal
J202: MS338-10F; MPN MS338-10F
J203: MS338-10C; MPN MS338-10C
JP201, JP202, JP203, JP204: Jumper_2_Bridged; PinHeader_1x02_P2.54mm_Vertical_SMD_Pin1Right; MPN 10129380-902001BLF or equivalent
L201: 33uH; L_Taiyo-Yuden_NR-5030; MPN LSXND5050XKT330MMG
L202: 47uH; L_Wurth_WE-LQSF-4828; MPN 74406043470
Q201: DMP3099L-7; SOT-23; MPN DMP3099L-7
R201: 200kR; R_0402_1005Metric; Tolerance 1%; MPN Generic R/200kR/0402/1%
R202: 1kR; R_0402_1005Metric; Tolerance 1%; MPN Generic R/1kR/0402/1%
R203: 47.5kR; R_0402_1005Metric; Tolerance 1%; MPN Generic R/47.5kR/0402/1%
R204: 110kR; R_0402_1005Metric; Tolerance 1%; MPN Generic R/110kR/0402/1%
R205, R206: 100kR; R_0402_1005Metric; Tolerance 1%; MPN Generic R/100kR/0402/1%
R207: 1.6kR; R_0402_1005Metric; Tolerance 1%; MPN Generic R/1.6kR/0402/1%
R208: 3.16kR; R_0402_1005Metric; Tolerance 1%; MPN Generic R/3.16kR/0402/1%
R209: 43kR; R_0402_1005Metric; Tolerance 0.1% or better; MPN Generic R/43kR/0402/0.1%
R210: 9.53kR; R_0402_1005Metric; Tolerance 0.1% or better; MPN Generic R/9.53kR/0402/0.1%
R211: 20kR; R_0402_1005Metric; Tolerance 0.1% or better; MPN Generic R/20kR/0402/0.1%
R212: 10kR; R_0402_1005Metric; Tolerance 0.1% or better; MPN Generic R/10kR/0402/0.1%
R213: 2.55kR; R_0402_1005Metric; Tolerance 1%; MPN Generic R/2.55kR/0402/1%
R214: 10.2kR; R_0402_1005Metric; Tolerance 0.1%; MPN Generic R/10.2kR/0402/0.1%
R301: 100R; R_0402_1005Metric; Tolerance 1%; MPN Generic R/100R/0402/1%
SW201: 436351045816; SW_SPST_436351045816; MPN 436351045816
TP201, TP202, TP203, TP204, TP205, TP206, TP207, TP208, TP209, TP210: TestPoint; Pin_D0.7mm_L6.5mm_W1.8mm_FlatFork
U201: LTC2954-1; TSOT-23-8; MPN LTC2954CTS8-1#TRMPBF
U202: TPS65261RHBx; VQFN-32-1EP_5x5mm_P0.5mm_EP3.45x3.45mm_ThermalVias; MPN TPS65261RHBR
U203: AP7330-W5-7; SOT-23-5; MPN AP7330-W5-7
U204: TPS22810DBVR; SOT-23-6; MPN TPS22810DBVR

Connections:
+1V0: JP204.2 (B); also elsewhere on the board
+1V8: C220.1, JP203.2 (B), TP203.1, U203.1 (V_{in}), U203.3 (EN); also elsewhere on the board
+3V3: JP202.2 (B), R205.1, R206.1, TP202.1; also elsewhere on the board
+BATT: C201.1, C206.1, C207.1, C208.1, C209.1, C210.1, C211.1, C227.1, Q201.2 (S), R201.1, R202.1, TP201.1, U202.12 (PVIN2), U202.28 (PVIN1), U202.29 (VIN), U204.6 (VIN); also elsewhere on the board
/Connectors/MAIN_KILL: U201.8 (~KILL); also elsewhere on the board
/Connectors/MCU_NRST: R206.2, U202.3 (RESET); also elsewhere on the board
/Connectors/PB_INT: U201.5 (~INT); also elsewhere on the board
/Power supply/PWR_EN: TP205.1, U201.6 (EN), U202.31 (EN1), U202.32 (EN2), U204.5 (EN/UVLO)
/Power supply/SS_CAP: C202.1, U202.8 (SS2), U202.24 (SS1)
GND: C201.2, C202.2, C203.2, C204.2, C205.2, C206.2, C207.2, C208.2, C209.2, C210.2, C211.2, C212.2, C213.2, C216.2, C217.2, C218.2, C219.2, C220.2, C221.2, C222.2, C223.2, C224.2, C225.2, C226.2, C227.2, J201.2, J202.1 (Shield), JP201.1 (A), Q201.1 (G), R204.2, R210.2, R212.2, R214.2, SW201.2, TP204.1, TP206.1, TP207.1, TP208.1, TP209.1, TP210.1, U201.4 (GND), U202.1 (EN3), U202.4 (MODE), U202.11 (PGND2), U202.13 (PVIN3), U202.14 (PGND3), U202.21 (AGND), U202.27 (PGND1), U202.33 (PAD), U203.2 (GND), U204.4 (GND); also elsewhere on the board
unnamed: F201.1, J201.1
unnamed: C216.1, R207.2
unnamed: C217.1, R208.2
unnamed: JP201.2 (B), R203.1
unnamed: C218.1, C221.1, C223.1, C228.1, JP202.1 (A), L201.2, R209.1
unnamed: C219.1, C222.1, C224.1, C229.1, JP203.1 (A), L202.2, R211.1
unnamed: C225.1, JP204.1 (A), R213.1, U203.5 (V_{out})
unnamed: F201.2, Q201.3 (D)
unnamed: C203.1, U201.3 (ONT)
unnamed: C204.1, U201.7 (PDT)
unnamed: R202.2, U201.1 (V_{in})
unnamed: SW201.1, U201.2 (~PB)
unnamed: R204.1, U202.20 (ROSC)
unnamed: C205.1, U202.5 (V7V)
unnamed: R201.2, R203.2, U202.30 (VDIV)
unnamed: C214.1, U202.25 (BST1)
unnamed: C212.1, R207.1, U202.23 (COMP1)
unnamed: C228.2, R209.2, R210.1, U202.22 (FB1)
unnamed: C214.2, L201.1, U202.26 (LX1)
unnamed: C215.1, U202.9 (BST2)
unnamed: C213.1, R208.1, U202.7 (COMP2)
unnamed: C229.2, R211.2, R212.1, U202.6 (FB2)
unnamed: C215.2, L202.1, U202.10 (LX2)
unnamed: R213.2, R214.1, U203.4 (ADJ)
unnamed: C226.1, U204.3 (CT)

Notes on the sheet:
For the calculations and details on dimensioning, see ./power_supply.md
Open this jumper to disable UVLO

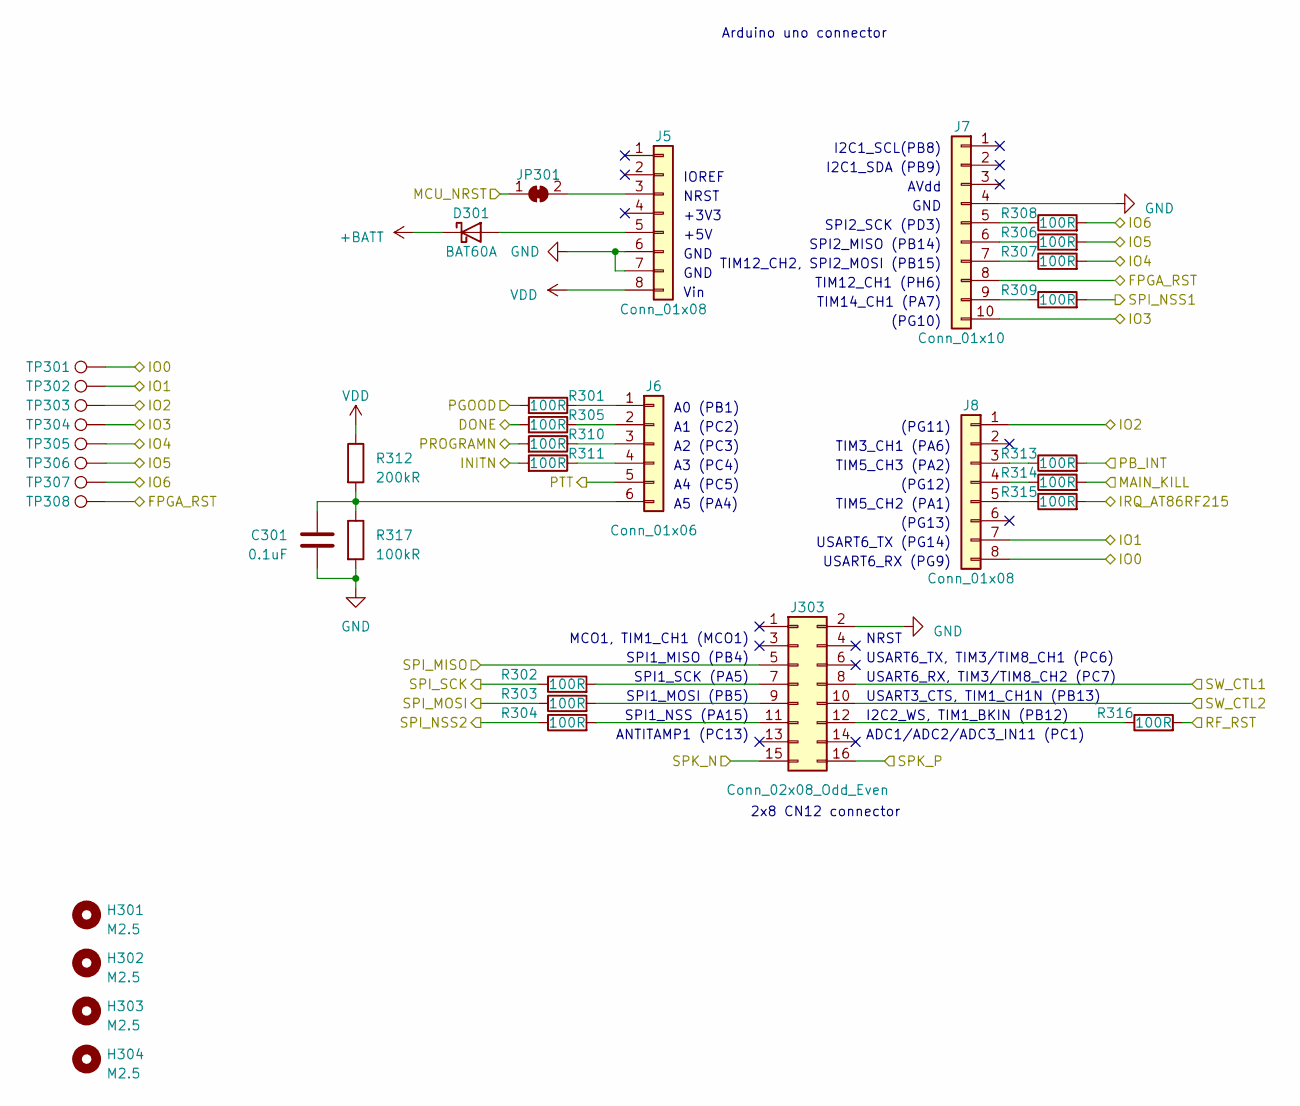
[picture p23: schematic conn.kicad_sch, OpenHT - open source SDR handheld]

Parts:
C301: 0.1uF; C_0402_1005Metric; MPN Generic C/0.1uF/0402/X7R/16V
D301: BAT60A; D_SOD-323; MPN BAT60AE6327HTSA1
H301, H302, H303, H304: M2.5; MountingHole_2.7mm_M2.5
J5, J8: Conn_01x08; PinHeader_1x08_P2.54mm_Vertical
J6: Conn_01x06; PinHeader_1x06_P2.54mm_Vertical
J7: Conn_01x10; PinHeader_1x10_P2.54mm_Vertical
J303: Conn_02x08_Odd_Even; PinSocket_2x08_P2.54mm_Vertical
JP301: SolderJumper_2_Bridged; SolderJumper-2_P1.3mm_Open_TrianglePad1.0x1.5mm
R301, R302, R303, R304, R305, R306, R307, R308, R309, R310, R311, R313, R314, R315, R316: 100R; R_0402_1005Metric; Tolerance 1%; MPN Generic R/100R/0402/1%
R312: 200kR; R_0402_1005Metric; Tolerance 1%; MPN Generic R/200kR/0402/1%
R317: 100kR; R_0402_1005Metric; Tolerance 1%; MPN Generic R/100kR/0402/1%
TP301, TP302, TP303, TP304, TP305, TP306, TP307, TP308: TestPoint; Pin_D0.7mm_L6.5mm_W1.8mm_FlatFork

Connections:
+BATT: D301.1 (K); also elsewhere on the board
/Connectors/DONE: R305.2; also elsewhere on the board
/Connectors/FPGA_RST: TP308.1; also elsewhere on the board
/Connectors/INITN: R311.2; also elsewhere on the board
/Connectors/IO0: TP301.1; also elsewhere on the board
/Connectors/IO1: TP302.1; also elsewhere on the board
/Connectors/IO2: TP303.1; also elsewhere on the board
/Connectors/IO3: TP304.1; also elsewhere on the board
/Connectors/IO4: R307.2, TP305.1; also elsewhere on the board
/Connectors/IO5: R306.2, TP306.1; also elsewhere on the board
/Connectors/IO6: R308.2, TP307.1; also elsewhere on the board
/Connectors/IRQ_AT86RF215: R315.2; also elsewhere on the board
/Connectors/MAIN_KILL: R314.2; also elsewhere on the board
/Connectors/MCU_NRST: JP301.1 (A); also elsewhere on the board
/Connectors/PB_INT: R313.2; also elsewhere on the board
/Connectors/PROGRAMN: R310.2; also elsewhere on the board
/Connectors/RF_RST: R316.2; also elsewhere on the board
/Connectors/SPI_NSS2: R304.1; also elsewhere on the board
/Connectors/SPK_N: J303.15; also elsewhere on the board
/Connectors/SPK_P: J303.16; also elsewhere on the board
/Connectors/SW_CTL1: J303.8; also elsewhere on the board
/Connectors/SW_CTL2: J303.10; also elsewhere on the board
/FPGA/TCK/SCLK: R302.1; also elsewhere on the board
/FPGA/TDI/SSI: R303.1; also elsewhere on the board
/FPGA/TDO/SSO: J303.5; also elsewhere on the board
/FPGA/TMS/SCSN: R309.2; also elsewhere on the board
GND: C301.2, J303.2, R317.2; also elsewhere on the board
unnamed 57: D301.2 (A); also elsewhere on the board
unnamed 63: R305.1; also elsewhere on the board
unnamed 64: R310.1; also elsewhere on the board
unnamed 65: R311.1; also elsewhere on the board
unnamed 66: C301.1, R312.2, R317.1; also elsewhere on the board
unnamed 67: JP301.2 (B); also elsewhere on the board
unnamed: J303.7, R302.2
unnamed: J303.9, R303.2
unnamed: J303.11, R304.2
unnamed: J303.12, R316.1
unnamed 72: R308.1; also elsewhere on the board
unnamed 73: R306.1; also elsewhere on the board
unnamed 74: R307.1; also elsewhere on the board
unnamed 75: R309.1; also elsewhere on the board
unnamed 76: R313.1; also elsewhere on the board
unnamed 77: R314.1; also elsewhere on the board
unnamed 78: R315.1; also elsewhere on the board

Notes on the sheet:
SPI1_MISO (PB4)
(PG12)
NRST
I2C1_SDA (PB9)
TIM12_CH1 (PH6)
A0 (PB1)
+5V
AVdd
I2C2_WS, TIM1_BKIN (PB12)
TIM3_CH1 (PA6)
I2C1_SCL(PB8)
TIM5_CH2 (PA1)
A4 (PC5)
USART6_TX (PG14)
USART6_RX, TIM3/TIM8_CH2 (PC7)
MCO1, TIM1_CH1 (MCO1)
SPI1_MOSI (PB5)
GND
SPI2_MISO (PB14)
SPI1_NSS (PA15)
USART6_RX (PG9)
(PG11)
(PG10)
IOREF
2x8 CN12 connector
USART6_TX, TIM3/TIM8_CH1 (PC6)
TIM12_CH2, SPI2_MOSI (PB15)
SPI1_SCK (PA5)
A1 (PC2)
A5 (PA4)
TIM14_CH1 (PA7)
ADC1/ADC2/ADC3_IN11 (PC1)
+3V3
SPI2_SCK (PD3)
Vin
A3 (PC4)
ANTITAMP1 (PC13)
Arduino uno connector
A2 (PC3)
TIM5_CH3 (PA2)

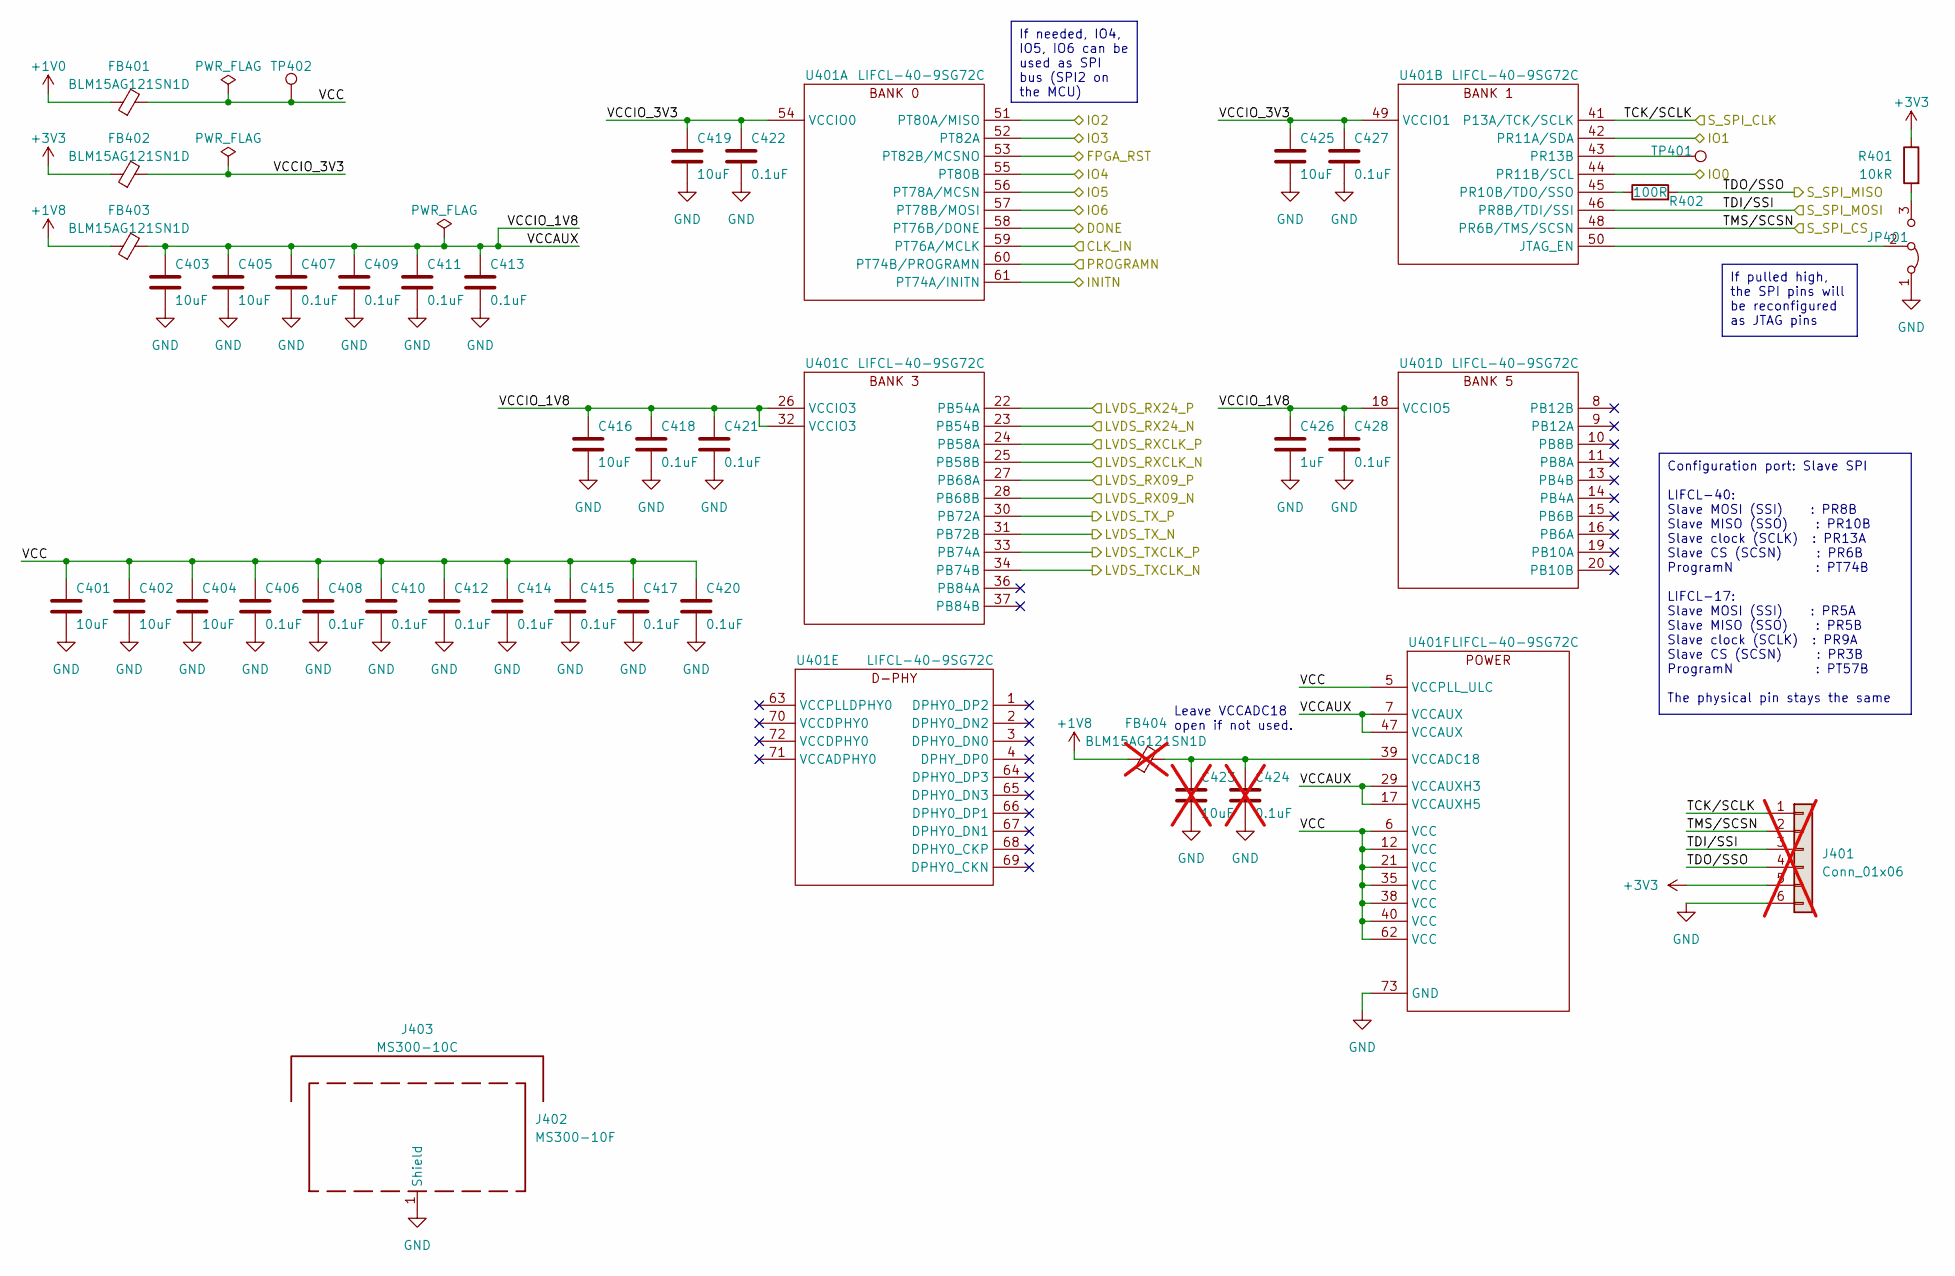
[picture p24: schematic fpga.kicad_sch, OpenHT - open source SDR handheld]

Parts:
C401, C402, C403, C404, C405, C416, C419, C425: 10uF; C_0805_2012Metric; MPN Generic C/10uF/0805/X5R/10V
C406, C407, C408, C409, C410, C411, C412, C413, C414, C415, C417, C418, C420, C421, C422, C427, C428: 0.1uF; C_0402_1005Metric; MPN Generic C/0.1uF/0402/X7R/16V
C423: 10uF; C_0805_2012Metric; MPN Generic C/10uF/0805/X5R/10V; not fitted
C424: 0.1uF; C_0402_1005Metric; MPN Generic C/0.1uF/0402/X7R/16V; not fitted
C426: 1uF; C_0402_1005Metric; MPN Generic C/1uF/0402/X5R/10V
FB401, FB402, FB403: BLM15AG121SN1D; L_0402_1005Metric; MPN BLM15AG121SN1D
FB404: BLM15AG121SN1D; L_0402_1005Metric; MPN BLM15AG121SN1D; not fitted
J401: Conn_01x06; PinSocket_1x06_P2.54mm_Horizontal; not fitted
J402: MS300-10F; MPN MS300-10F
J403: MS300-10C; MPN MS300-10C
JP401: Jumper_3_Bridged12; PinHeader_1x03_P2.54mm_Vertical
R401: 10kR; R_0402_1005Metric; Tolerance 1%; MPN Generic R/10kR/0402/1%
R402: 100R; R_0402_1005Metric; Tolerance 1%; MPN Generic R/100R/0402/1%
TP401, TP402: TestPoint; Pin_D0.7mm_L6.5mm_W1.8mm_FlatFork
U401: LIFCL-40-9SG72C; QFN-72-1EP_10x10mm_P0.5mm_EP6.2x6.2mm_ThermalVias; MPN LIFCL-40-9SG72C

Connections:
+1V0: FB401.1; also elsewhere on the board
+1V8: FB403.1, FB404.1; also elsewhere on the board
+3V3: FB402.1, J401.5, R401.1; also elsewhere on the board
/Connectors/DONE: U401.58 (PT76B/DONE); also elsewhere on the board
/Connectors/FPGA_RST: U401.53 (PT82B/MCSNO); also elsewhere on the board
/Connectors/INITN: U401.61 (PT74A/INITN); also elsewhere on the board
/Connectors/IO0: U401.44 (PR11B/SCL); also elsewhere on the board
/Connectors/IO1: U401.42 (PR11A/SDA); also elsewhere on the board
/Connectors/IO2: U401.51 (PT80A/MISO); also elsewhere on the board
/Connectors/IO3: U401.52 (PT82A); also elsewhere on the board
/Connectors/IO4: U401.55 (PT80B); also elsewhere on the board
/Connectors/IO5: U401.56 (PT78A/MCSN); also elsewhere on the board
/Connectors/IO6: U401.57 (PT78B/MOSI); also elsewhere on the board
/Connectors/PROGRAMN: U401.60 (PT74B/PROGRAMN); also elsewhere on the board
/FPGA/CLK_IN: U401.59 (PT76A/MCLK); also elsewhere on the board
/FPGA/LVDS_RX09_N: U401.28 (PB68B); also elsewhere on the board
/FPGA/LVDS_RX09_P: U401.27 (PB68A); also elsewhere on the board
/FPGA/LVDS_RX24_N: U401.23 (PB54B); also elsewhere on the board
/FPGA/LVDS_RX24_P: U401.22 (PB54A); also elsewhere on the board
/FPGA/LVDS_RXCLK_N: U401.25 (PB58B); also elsewhere on the board
/FPGA/LVDS_RXCLK_P: U401.24 (PB58A); also elsewhere on the board
/FPGA/LVDS_TXCLK_N: U401.34 (PB74B); also elsewhere on the board
/FPGA/LVDS_TXCLK_P: U401.33 (PB74A); also elsewhere on the board
/FPGA/LVDS_TX_N: U401.31 (PB72B); also elsewhere on the board
/FPGA/LVDS_TX_P: U401.30 (PB72A); also elsewhere on the board
/FPGA/TCK/SCLK: J401.1, U401.41 (P13A/TCK/SCLK); also elsewhere on the board
/FPGA/TDI/SSI: J401.3, U401.46 (PR8B/TDI/SSI); also elsewhere on the board
/FPGA/TDO/SSO: J401.4, R402.2; also elsewhere on the board
/FPGA/TMS/SCSN: J401.2, U401.48 (PR6B/TMS/SCSN); also elsewhere on the board
/FPGA/VCC: C401.1, C402.1, C404.1, C406.1, C408.1, C410.1, C412.1, C414.1, C415.1, C417.1, C420.1, FB401.2, TP402.1, U401.5 (VCCPLL_ULC), U401.6 (VCC), U401.12 (VCC), U401.21 (VCC), U401.35 (VCC), U401.38 (VCC), U401.40 (VCC), U401.62 (VCC)
/FPGA/VCCAUX: C403.1, C405.1, C407.1, C409.1, C411.1, C413.1, C416.1, C418.1, C421.1, C426.1, C428.1, FB403.2, U401.7 (VCCAUX), U401.17 (VCCAUXH5), U401.18 (VCCIO5), U401.26 (VCCIO3), U401.29 (VCCAUXH3), U401.32 (VCCIO3), U401.47 (VCCAUX)
/FPGA/VCCIO_3V3: C419.1, C422.1, C425.1, C427.1, FB402.2, U401.49 (VCCIO1), U401.54 (VCCIO0)
GND: C401.2, C402.2, C403.2, C404.2, C405.2, C406.2, C407.2, C408.2, C409.2, C410.2, C411.2, C412.2, C413.2, C414.2, C415.2, C416.2, C417.2, C418.2, C419.2, C420.2, C421.2, C422.2, C423.2, C424.2, C425.2, C426.2, C427.2, C428.2, J401.6, J402.1 (Shield), JP401.1 (A), U401.73 (GND); also elsewhere on the board
unnamed: JP401.3 (B), R401.2
unnamed: JP401.2 (C), U401.50 (JTAG_EN)
unnamed: TP401.1, U401.43 (PR13B)
unnamed: C423.1, C424.1, FB404.2, U401.39 (VCCADC18)

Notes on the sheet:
If needed, IO4, IO5, IO6 can be used as SPI bus (SPI2 on the MCU)
If pulled high, the SPI pins will be reconfigured as JTAG pins
Configuration port: Slave SPI LIFCL-40: Slave MOSI (SSI) : PR8B Slave MISO (SSO) : PR10B Slave clock (SCLK) : PR13A Slave CS (SCSN) : PR6B ProgramN : PT74B LIFCL-17: Slave MOSI (SSI) : PR5A Slave MISO (SSO) : PR5B Slave clock (SCLK) : PR9A Slave CS (SCSN) : PR3B ProgramN : PT57B The physical pin st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
Leave VCCADC18 open if not used.

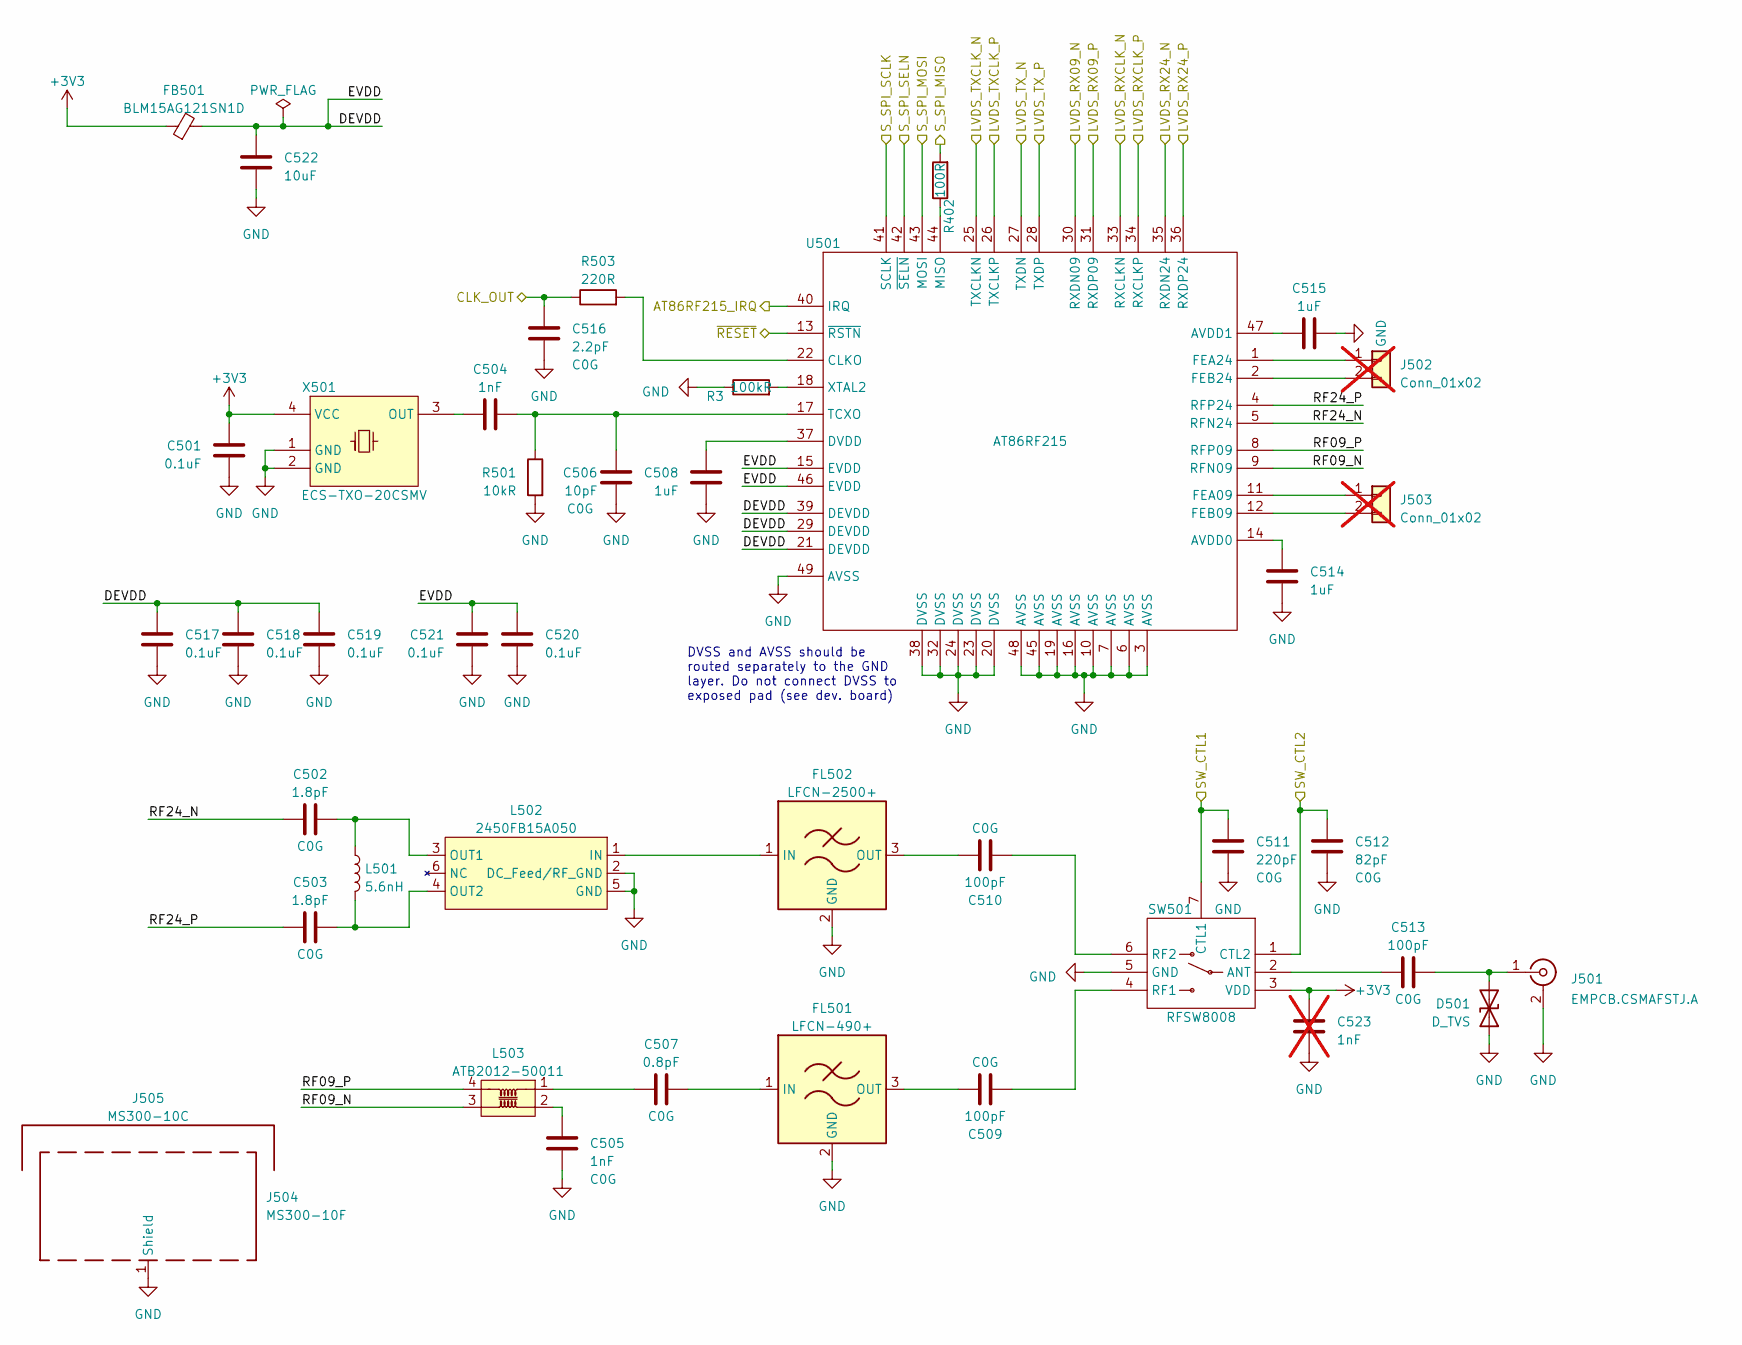
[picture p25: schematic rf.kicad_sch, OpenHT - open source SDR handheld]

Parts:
C501, C517, C518, C519, C520, C521: 0.1uF; C_0402_1005Metric; MPN Generic C/0.1uF/0402/X7R/16V
C502, C503: 1.8pF; C_0402_1005Metric; MPN Generic C/1.8pF/0402/C0G/10V
C504: 1nF; C_0402_1005Metric; MPN Generic C/1nF/0402/X7R/10V
C505: 1nF; C_0402_1005Metric; MPN Generic C/1nF/0402/C0G/10V
C506: 10pF; C_0402_1005Metric; MPN Generic C/10pF/0402/C0G/10V
C507: 0.8pF; C_0402_1005Metric; MPN Generic C/0.8pF/0402/C0G/10V
C508, C514, C515: 1uF; C_0402_1005Metric; MPN Generic C/1uF/0402/X5R/10V
C509, C510, C513: 100pF; C_0402_1005Metric; MPN Generic C/100pF/0402/C0G/10V
C511: 220pF; C_0402_1005Metric; MPN Generic C/220pF/0402/C0G/10V
C512: 82pF; C_0402_1005Metric; MPN Generic C/82pF/0402/C0G/10V
C516: 2.2pF; C_0402_1005Metric; MPN Generic C/2.2pF/0402/C0G/10V
C522: 10uF; C_0805_2012Metric; MPN Generic C/10uF/0805/X5R/10V
C523: 1nF; C_0402_1005Metric; MPN Generic C/1nF/0402/X7R/10V; not fitted
D501: D_TVS; D_Toshiba_CST2; MPN DF2B5M4CT,L3F
FB501: BLM15AG121SN1D; L_0402_1005Metric; MPN BLM15AG121SN1D
FL501: LFCN-490+; Filter_Mini-Circuits_FV1206; MPN LFCN-490+
FL502: LFCN-2500+; Filter_Mini-Circuits_FV1206; MPN LFCN-2500+
J501: EMPCB.CSMAFSTJ.A; SMA_Taoglas_EMPCB.CSMAFSTJ.A; MPN EMPCB.CSMAFSTJ.A
J502, J503: Conn_01x02; PinHeader_1x02_P2.54mm_Vertical; not fitted
J504: MS300-10F; MPN MS300-10F
J505: MS300-10C; MPN MS300-10C
L501: 5.6nH; L_0402_1005Metric; MPN LRC0402CS5N6GV001T
L502: 2450FB15A050; MPN 2450FB15A0050001E
L503: ATB2012-50011; ATB2012; MPN ATB2012-50011-T000
R3: 100kR; R_0402_1005Metric; Tolerance 1%; MPN Generic R/100kR/0402/1%
R402: 100R; R_0402_1005Metric; Tolerance 1%; MPN Generic R/100R/0402/1%
R501: 10kR; R_0402_1005Metric; Tolerance 1%; MPN Generic R/10kR/0402/1%
R503: 220R; R_0402_1005Metric; Tolerance 1%; MPN Generic R/220R/0402/1%
SW501: RFSW8008; MPN RFSW8008TR7
U501: AT86RF215; VQFN-48-1EP_7x7mm_P0.5mm_EP5.6x5.6mm_ThermalVias; MPN AT86RF215-ZU
X501: ECS-TXO-20CSMV; MPN ECS-TXO-20CSMV-260-AY-TR

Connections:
+3V3: C501.1, C523.1, FB501.1, SW501.3 (VDD), X501.4 (VCC); also elsewhere on the board
/Connectors/IRQ_AT86RF215: U501.40 (IRQ); also elsewhere on the board
/Connectors/RF_RST: U501.13 (~RSTN); also elsewhere on the board
/Connectors/SPI_NSS2: U501.42 (~SELN); also elsewhere on the board
/Connectors/SW_CTL1: C511.1, SW501.7 (CTL1); also elsewhere on the board
/Connectors/SW_CTL2: C512.1, SW501.1 (CTL2); also elsewhere on the board
/FPGA/CLK_IN: C516.1, R503.1; also elsewhere on the board
/FPGA/LVDS_RX09_N: U501.30 (RXDN09); also elsewhere on the board
/FPGA/LVDS_RX09_P: U501.31 (RXDP09); also elsewhere on the board
/FPGA/LVDS_RX24_N: U501.35 (RXDN24); also elsewhere on the board
/FPGA/LVDS_RX24_P: U501.36 (RXDP24); also elsewhere on the board
/FPGA/LVDS_RXCLK_N: U501.33 (RXCLKN); also elsewhere on the board
/FPGA/LVDS_RXCLK_P: U501.34 (RXCLKP); also elsewhere on the board
/FPGA/LVDS_TXCLK_N: U501.25 (TXCLKN); also elsewhere on the board
/FPGA/LVDS_TXCLK_P: U501.26 (TXCLKP); also elsewhere on the board
/FPGA/LVDS_TX_N: U501.27 (TXDN); also elsewhere on the board
/FPGA/LVDS_TX_P: U501.28 (TXDP); also elsewhere on the board
/FPGA/TCK/SCLK: U501.41 (SCLK); also elsewhere on the board
/FPGA/TDI/SSI: U501.43 (MOSI); also elsewhere on the board
/FPGA/TDO/SSO: R402.2; also elsewhere on the board
/RF/DEVDD: C517.1, C518.1, C519.1, C520.1, C521.1, C522.1, FB501.2, U501.15 (EVDD), U501.21 (DEVDD), U501.29 (DEVDD), U501.39 (DEVDD), U501.46 (EVDD)
/RF/RF09_N: L503.3, U501.9 (RFN09)
/RF/RF09_P: L503.4, U501.8 (RFP09)
/RF/RF24_N: C502.1, U501.5 (RFN24)
/RF/RF24_P: C503.1, U501.4 (RFP24)
GND: C501.2, C505.2, C506.2, C508.2, C511.2, C512.2, C514.2, C515.2, C516.2, C517.2, C518.2, C519.2, C520.2, C521.2, C522.2, C523.2, D501.1 (A1), FL501.2 (GND), FL501.4 (GND), FL502.2 (GND), FL502.4 (GND), J501.2 (Ext), J504.1 (Shield), L502.2 (DC_Feed/RF_GND), L502.5 (GND), R501.2, SW501.5 (GND), U501.3 (AVSS), U501.6 (AVSS), U501.7 (AVSS), U501.10 (AVSS), U501.16 (AVSS), U501.19 (AVSS), U501.20 (DVSS), U501.23 (DVSS), U501.24 (DVSS), U501.32 (DVSS), U501.38 (DVSS), U501.45 (AVSS), U501.48 (AVSS), U501.49 (AVSS), X501.1 (GND), X501.2 (GND); also elsewhere on the board
unnamed: C505.1, L503.2
unnamed: C507.1, L503.1
unnamed: C513.2, D501.2 (A2), J501.1 (In)
unnamed: C507.2, FL501.1 (IN)
unnamed: C509.1, FL501.3 (OUT)
unnamed: FL502.1 (IN), L502.1 (IN)
unnamed: C510.1, FL502.3 (OUT)
unnamed: J502.1, U501.1 (FEA24)
unnamed: J502.2, U501.2 (FEB24)
unnamed: J503.1, U501.11 (FEA09)
unnamed: J503.2, U501.12 (FEB09)
unnamed: C502.2, L501.1, L502.3 (OUT1)
unnamed: C503.2, L501.2, L502.4 (OUT2)
unnamed: C513.1, SW501.2 (ANT)
unnamed: C509.2, SW501.4 (RF1)
unnamed: C510.2, SW501.6 (RF2)
unnamed: C514.1, U501.14 (AVDD0)
unnamed: C515.1, U501.47 (AVDD1)
unnamed: R503.2, U501.22 (CLKO)
unnamed: C508.1, U501.37 (DVDD)
unnamed: C504.2, C506.1, R501.1, U501.17 (TCXO)
unnamed 120: U501.18 (XTAL2); also elsewhere on the board
unnamed: C504.1, X501.3 (OUT)

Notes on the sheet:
DVSS and AVSS should be routed separately to the GND layer. Do not connect DVSS to exposed pad (see dev. board)

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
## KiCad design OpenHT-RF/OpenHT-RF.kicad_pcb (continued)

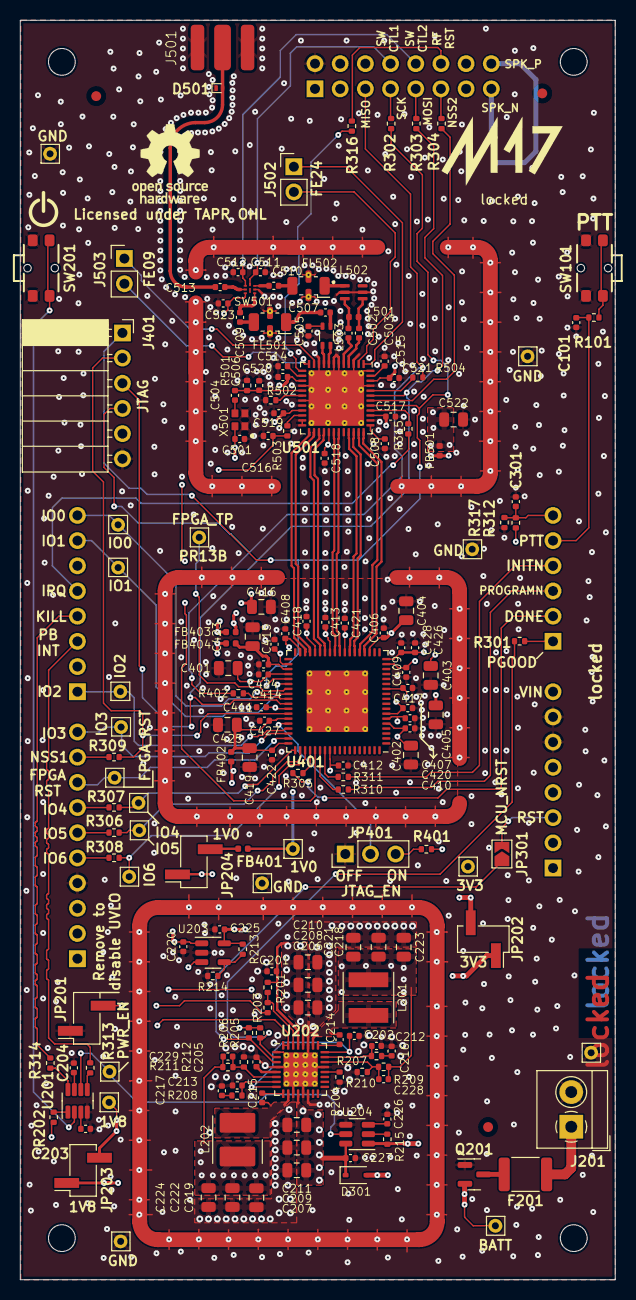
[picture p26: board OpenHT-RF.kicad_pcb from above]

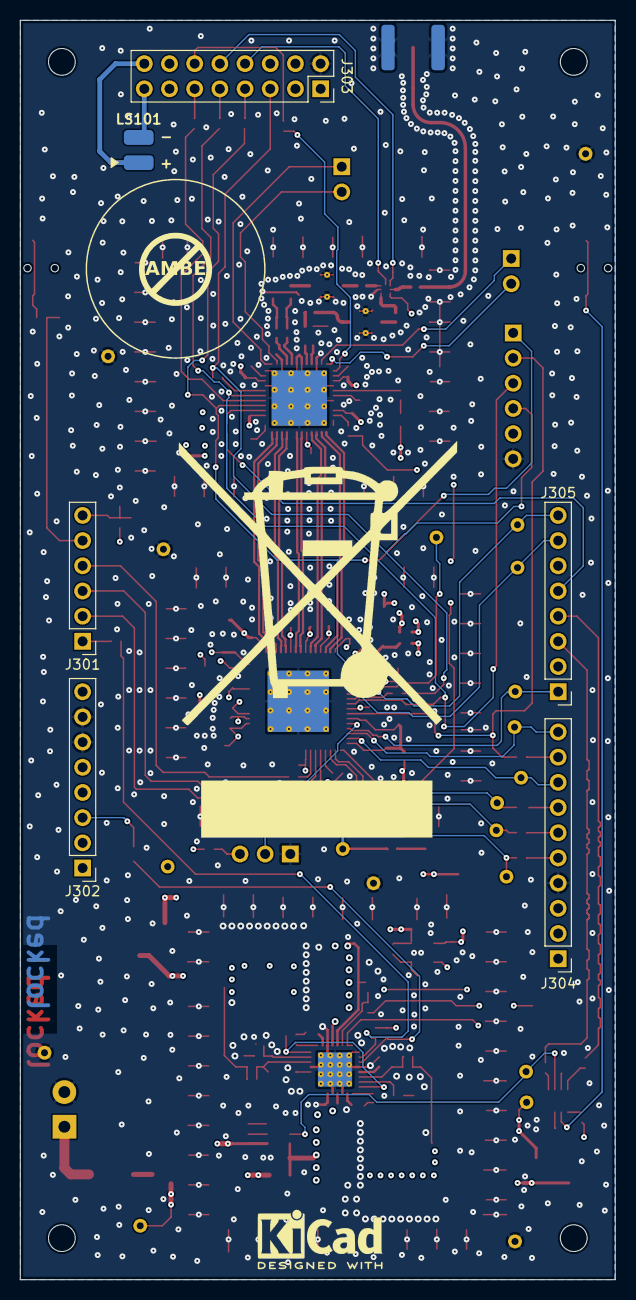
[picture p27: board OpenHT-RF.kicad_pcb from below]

Board: 4 copper layers, 60.0 x 127.0 mm, 198 parts (8 on the bottom side), 128 nets.

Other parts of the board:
C101: 1uF; C_0402_1005Metric
G1: KiCad-Logo2_5mm_SilkScreen
J301: Conn_01x06; PinHeader_1x06_P2.54mm_Vertical
J302, J305: Conn_01x08; PinHeader_1x08_P2.54mm_Vertical
J304: Conn_01x10; PinHeader_1x10_P2.54mm_Vertical
R101: 1kR; R_0402_1005Metric
R215, R504: 100R; R_0402_1005Metric
R502: 100kR; R_0402_1005Metric
SW101: 436351045816; SW_SPST_436351045816
WEEE01: WEEE-Logo_28.1x40mm_SilkScreen

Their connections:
/Connectors/FPGA_RST: J304.8; also elsewhere on the board
/Connectors/IO0: J305.8; also elsewhere on the board
/Connectors/IO1: J305.7; also elsewhere on the board
/Connectors/IO2: J305.1; also elsewhere on the board
/Connectors/IO3: J304.10; also elsewhere on the board
/Connectors/PTT: C101.1, J301.5, R101.2
/FPGA/TDO/SSO: R504.2; also elsewhere on the board
GND: C101.2, J302.6, J302.7, J304.4, R502.1, SW101.1; also elsewhere on the board
unnamed 57: J302.5; also elsewhere on the board
unnamed 63: J301.2; also elsewhere on the board
unnamed 64: J301.3; also elsewhere on the board
unnamed 65: J301.4; also elsewhere on the board
unnamed 66: J301.6; also elsewhere on the board
unnamed 67: J302.3; also elsewhere on the board
unnamed 72: J304.5; also elsewhere on the board
unnamed 73: J304.6; also elsewhere on the board
unnamed 74: J304.7; also elsewhere on the board
unnamed 75: J304.9; also elsewhere on the board
unnamed 76: J305.3; also elsewhere on the board
unnamed 77: J305.4; also elsewhere on the board
unnamed 78: J305.5; also elsewhere on the board
unnamed: R101.1, SW101.2
unnamed 120: R502.2; also elsewhere on the board

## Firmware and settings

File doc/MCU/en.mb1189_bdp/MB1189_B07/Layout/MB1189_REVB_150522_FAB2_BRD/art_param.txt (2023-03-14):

DEVICE-TYPE           GERBER_RS274X
OUTPUT-UNITS          INCHES
FILM-SIZE             10000000 8000000
FORMAT                3.5
ABORT-ON-ERROR        NO
SCALE                 1
SUPPRESS-LEAD-ZEROES  YES
SUPPRESS-TRAIL-ZEROES NO
SUPPRESS-EQUAL        YES
UNDEF-APT-CONT        NO

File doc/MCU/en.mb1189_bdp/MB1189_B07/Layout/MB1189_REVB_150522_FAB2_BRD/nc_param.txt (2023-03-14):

INTEGER-PLACES         3
DECIMAL-PLACES         5
X-OFFSET               0.000000
Y-OFFSET               0.000000
FEEDRATE               1
COORDINATES            ABSOLUTE
OUTPUT-UNITS           ENGLISH
TOOL-ORDER             INCREASING
REPEAT-CODES           NO
SUPPRESS-LEAD-ZEROES   YES
SUPPRESS-TRAIL-ZEROES  NO
SUPPRESS-EQUAL         YES
TOOL-SELECT            NO
OPTIMIZE_DRILLING      NO
ENHANCED_EXCELLON      YES
HEADER                 none
LEADER                 12
CODE                   ASCII
SEPARATE               NO
DRILLING               LAYER-PAIR
BACKDRILL              NO

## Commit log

2023-02-12 Created KiCad project for RF board
    [OpenHT-RF.kicad_pcb, OpenHT-RF.kicad_sch]
2023-02-15 project file upgraded to kicad v7.0
    [OpenHT-RF.kicad_sch]
2023-02-17 lfcn-490 filter added
    [OpenHT-RF.kicad_sch, conn.kicad_sch, fpga.kicad_sch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]
2023-02-18 pdf fix
    frame was missing
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2023-02-19 Added description of Arduino connectors
    [conn.kicad_sch]
2023-02-19 Added FPGA power rails
    [fpga.kicad_sch]
2023-02-20 FPGA diagram [WIP]
    [OpenHT-RF.kicad_sch, conn.kicad_sch, fpga.kicad_sch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]
2023-02-21 Added FPGA documentation
    [FPGA-SC-02015-1-1-LIFCL_QFN72_Pin_Migration.csv]
2023-02-21 Updated FPGA, RF and connectors sheets [WIP]
    [OpenHT-RF.kicad_sch, conn.kicad_sch, fpga.kicad_sch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]
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2023-02-22 Updated FPGA schematic to use M17_kicad_library
    [fpga.kicad_sch]
2023-02-22 Updated M17_kicad_library
    [fpga.kicad_sch]
2023-02-23 Updated RF schematic
    [rf.kicad_sch]
2023-02-25 Updated power supply schematic
    [pwr.kicad_sch]
2023-02-26 Added RF baluns
    [rf.kicad_sch]
2023-02-27 Added pushbutton controller for main power
    [OpenHT-RF.kicad_sch, pwr.kicad_sch]
2023-02-28 Updated FPGA power supply
    Design updated according to Lattice Hardware Checklist (https://www.latticesemi.com/view_document?document_id=52782)
    [fpga.kicad_sch]
2023-02-28 Fixed FPGA power supply
    vccio_1V8 is now correctly connected to 1V8
    [fpga.kicad_sch]
2023-03-05 [WIP]Updating power suply diagram
    Changing buck converter IC
    [OpenHT-RF.kicad_sch, pwr.kicad_sch]
2023-03-07 [WIP] Power supply diagram
    [pwr.kicad_sch]
2023-03-08 Finished power supply design
    [OpenHT-RF.kicad_sch, conn.kicad_sch, pwr.kicad_sch]
2023-03-08 Optimised IO routing, renumbered components
    [OpenHT-RF.kicad_sch, conn.kicad_sch, fpga.kicad_sch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]
2023-03-08 Updated net classes
    [rf.kicad_sch]
2023-03-09 Swapped AP7330 with AP7330D
    [pwr.kicad_sch]
2023-03-09 Added MPN for ferrite beads
    [fpga.kicad_sch, rf.kicad_sch]
2023-03-09 Updated PTT debounce circuit
    [OpenHT-RF.kicad_sch]
2023-03-09 Updated RF schematic
    Added low-pass filter at CLKO, updated capacitor values to AVDD and VDD according to dev. board files
    [rf.kicad_sch]
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2023-03-09 Updated power routing, added test points
    [conn.kicad_sch, pwr.kicad_sch]
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2023-03-12 Fixed CLKOUT low pass filter
    [rf.kicad_sch]
2023-03-12 Fixed BST capacitor placement
    [pwr.kicad_sch]
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2023-03-13 Imported components on PCB
    [OpenHT-RF.kicad_pcb]
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2023-03-13 Fixed 3.3V power symbol
    Use 3V3 everywhere instead of 3.3
    [OpenHT-RF.kicad_pcb, conn.kicad_sch, fpga.kicad_sch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]
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2023-03-14 Swapped LVDS pairs order
    [fpga.kicad_sch]
2023-03-14 Renamed RF differential signals
    [rf.kicad_sch]
2023-03-14 Added missing decoupling capacitors
    [rf.kicad_sch]
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2023-03-14 [WIP] Layout
    Connectors are now correctly placed for the Nucleo Board
    [OpenHT-RF.kicad_pcb]
2023-03-14 Added documentation for XCVR and MCU
    [AUDIO2.SchDoc, Arduino_ Connectors.SchDoc, Assembly Testpoint Report for REB215_XPRO_A.csv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]
2023-03-15 Updated speaker footprint
    Using SMD footprint
    [OpenHT-RF.kicad_sch]
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2023-03-15 [WIP] Layout
    Routed FPGA IOs and LVDS pairs
    [OpenHT-RF.kicad_pcb]
2023-03-16 [WIP] Layout
    Flipped the content upside down for the SMA connector. Reorganized GPIOs. RF routing started.
    [OpenHT-RF.kicad_pcb, conn.kicad_sch, fpga.kicad_sch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]
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2023-03-26 Added a load switch for the nucleo board
    [pwr.kicad_sch]
2023-03-26 Added battery measurement pin
    [conn.kicad_sch]
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2023-03-31 Various schematic updates
    Edited IO names, updated load switch symbol, swapped RF switch inputs
    [OpenHT-RF.kicad_sch, conn.kicad_sch, fpga.kicad_sch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]
2023-03-31 Updated PCB layout + step file
    PTT and power button now in their final location
    [OpenHT-RF.kicad_pcb]
2023-04-03 Updated push button footprint
    Now includes 3D model
    [OpenHT-RF.kicad_pcb]
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2023-04-07 Routed FPGA power supply tracks
    [OpenHT-RF.kicad_pcb]
2023-04-12 Added power supply decoupling capacitor
    [rf.kicad_sch]
2023-04-12 Power supply routing
    Finished routing power to the transceiver
    [OpenHT-RF.kicad_pcb]
2023-04-16 Various updates
    Updated some nets to ease up routing
    Updated testpoints to smaller size
    Added DNP capacitor next to RF switch
    [conn.kicad_sch, fpga.kicad_sch, pwr.kicad_sch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]
2023-04-16 [WIP] PCB Routing
    Routed most of the board.
    [OpenHT-RF.kicad_pcb]
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2023-04-28 Layout improvements and current measurement jumpers
    [OpenHT-RF.kicad_pcb, OpenHT-RF.kicad_sch, pwr.kicad_sch]
2023-05-02 Layout improvements and reverse polarity protection
    [OpenHT-RF.kicad_pcb, pwr.kicad_sch]
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2023-05-09 Updated incorrect capacitor footprint
    [OpenHT-RF.kicad_sch]
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2023-05-10 Added OSHW logo, gnd TP and via stitching
    Also added comments, revision number, and an easter egg
    [OpenHT-RF.kicad_pcb, OpenHT-RF.kicad_sch, conn.kicad_sch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]
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2023-05-11 Added missing MPN
    [pwr.kicad_sch]
2023-05-11 Added NO AMBE logo
    [OpenHT-RF.kicad_sch]
2023-05-11 Silkscreen layout and logos
    [OpenHT-RF.kicad_pcb]
2023-05-12 Added Leo Hofer's Callsign
    [OpenHT-RF.kicad_sch, conn.kicad_sch, fpga.kicad_sch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]
2023-05-12 Fixed ERC errors
    [fpga.kicad_sch, pwr.kicad_sch, rf.kicad_sch]
2023-05-12 Fixed DRC
    [OpenHT-RF.kicad_pcb]
2023-05-13 Fixed location of L502 silkscreen label
    [OpenHT-RF.kicad_pcb]
2023-05-14 Added polyfuse MPN to PCB
    [OpenHT-RF.kicad_pcb]
2023-05-14 Modified shields to use two symbols
    Allows to have the MPN of the lid in the schematic alongside the frame
    [OpenHT-RF.kicad_pcb, fpga.kicad_sch, pwr.kicad_sch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]
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2023-05-14 Completed components values
    Completed dielectric, rated voltage, tolerance, MPN
    [OpenHT-RF.kicad_sch, conn.kicad_sch, fpga.kicad_sch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]
2023-05-14 Added complete bom file
    [OpenHT-RF_bom.ods]
2023-05-15 Fixed incorrect value for R502
    [OpenHT-RF.kicad_pcb, rf.kicad_sch]
2023-05-15 Exclude fiducials from bom
    [OpenHT-RF.kicad_pcb]
2023-05-15 Added MPN for L501
    [OpenHT-RF.kicad_pcb, rf.kicad_sch]
2023-05-15 Added MPN for speaker
    [OpenHT-RF.kicad_pcb, OpenHT-RF.kicad_sch]
2023-05-15 Added MPN for SMD jumpers
    [OpenHT-RF.kicad_pcb, pwr.kicad_sch]
2023-05-15 Fixed tolerance for R214
    [OpenHT-RF.kicad_pcb, pwr.kicad_sch]
2023-05-15 Set 100nF to 0.1uF
    [OpenHT-RF.kicad_pcb]
2023-05-15 Added MPN for generic components
    [OpenHT-RF.kicad_pcb, OpenHT-RF.kicad_sch, conn.kicad_sch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]
2023-05-15 Various minor pcb updated
    [OpenHT-RF.kicad_pcb]
2023-05-15 Updated BOM and pdf schematic
    [OpenHT-RF_bom.ods]
2023-05-16 Fixed incorrect MPN for 4.7uF capacitors
    [OpenHT-RF.kicad_pcb, pwr.kicad_sch]
2023-05-16 Modified netclasses and controlled impedance tracks
    [OpenHT-RF.kicad_pcb]
2023-05-16 Fixed differential pairs and RF related DRC errors
    [OpenHT-RF.kicad_pcb, rf.kicad_sch]
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

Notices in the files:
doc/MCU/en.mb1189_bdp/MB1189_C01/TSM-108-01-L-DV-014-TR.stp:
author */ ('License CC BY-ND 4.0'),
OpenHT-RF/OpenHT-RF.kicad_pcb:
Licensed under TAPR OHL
